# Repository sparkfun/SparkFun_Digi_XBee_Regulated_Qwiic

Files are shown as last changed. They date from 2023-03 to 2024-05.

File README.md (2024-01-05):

SparkFun Digi XBee® Explorer Regulated
========================================

SparkFun Digi XBee® Explorer Regulated (https://www.sparkfun.com/products/22032)

[*SparkFun Digi XBee® Explorer Regulated (22032)*](https://www.sparkfun.com/products/22032)

Unleash the power of Digi XBee® modules with the next-gen SparkFun Digi XBee® Explorer Regulated! This versatile breakout board bypasses a USB-C connection, packing all the XBee functionality you need alongside the power of Digi's newest XBee 3 modules (XBee 3 LTE-M/NB-IoT and XBee RR Pro) into a single, convenient solution. The SparkFun Digi XBee® Explorer Regulated is the perfect companion for any low-power cellular IoT project. Its simplicity, versatility, and robust features make it ideal for beginners and seasoned developers.

The SparkFun Digi XBee® Explorer Regulated streamlines your workflow, providing everything you need to get started. Power is provided through the PTH headers, and the board retains its power regulation capabilities. You can enable the Qwiic connector for all those lovely I<sup>2</sup>C sensors and Reset and D0 buttons.

Repository Contents
-------------------

* **/Hardware** - Eagle design files (.brd, .sch)
* **/Production** - Production panel files (.brd)
* **/docs** - Related software for the Sparkfun Digi XBee® Arduino Shield

Documentation
--------------
* **[Hookup Guide](http://docs.sparkfun.com/SparkFun_Digi_XBee_Regulated_Qwiic)** - Basic hookup guide for the SparkFun Digi XBee® Explorer Regulated.

License Information
-------------------

This product is _**open source**_! 

Please review the LICENSE.md file for license information. 

If you have any questions or concerns on licensing, please contact technical support on our [SparkFun forums](https://forum.sparkfun.com/viewforum.php?f=152).

Distributed as-is; no warranty is given.

- Your friends at SparkFun.

_<COLLABORATION CREDIT>_

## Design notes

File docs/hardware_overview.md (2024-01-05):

---
icon: material/cog
---

## Digi XBee Smart Modem Socket

We've kept the Digi XBee socket consistent with the Digi XBee pinout, so this breakout board is backwards compatible. In order to take full advantage of this board, we recommend one of the newer Digi XBee boards. The [Digi XBee 3 Low-Power LTE-M/NB-IoT, GNSS, no SIM](https://www.sparkfun.com/products/22329) is a great bet. 

<figure markdown>
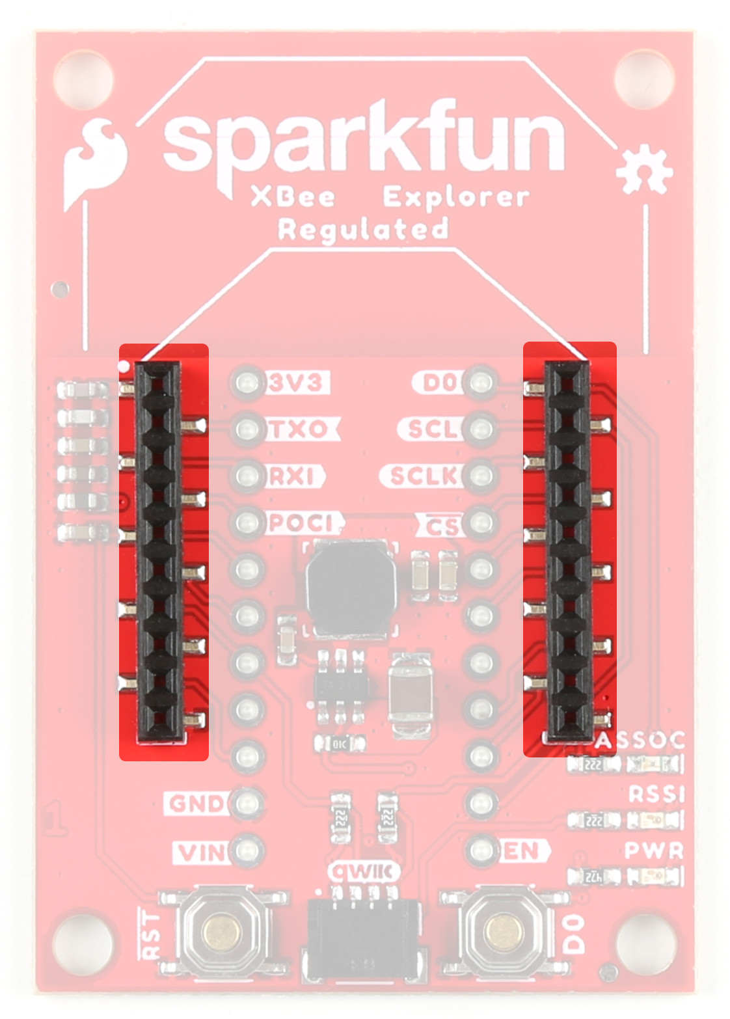
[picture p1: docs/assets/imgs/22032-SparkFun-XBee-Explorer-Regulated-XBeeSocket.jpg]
Digi XBeeSocket

<figcaption markdown>XBeeSocket</figcaption>
</figure>

## Qwiic Connector

The Qwiic connector on the SparkFun Digi XBee® Explorer Regulated Board provides power and I<sup>2</sup>C connectivity to Qwiic breakout boards. Note that I<sup>2</sup>C functionality is not enabled by default. 

<figure markdown>
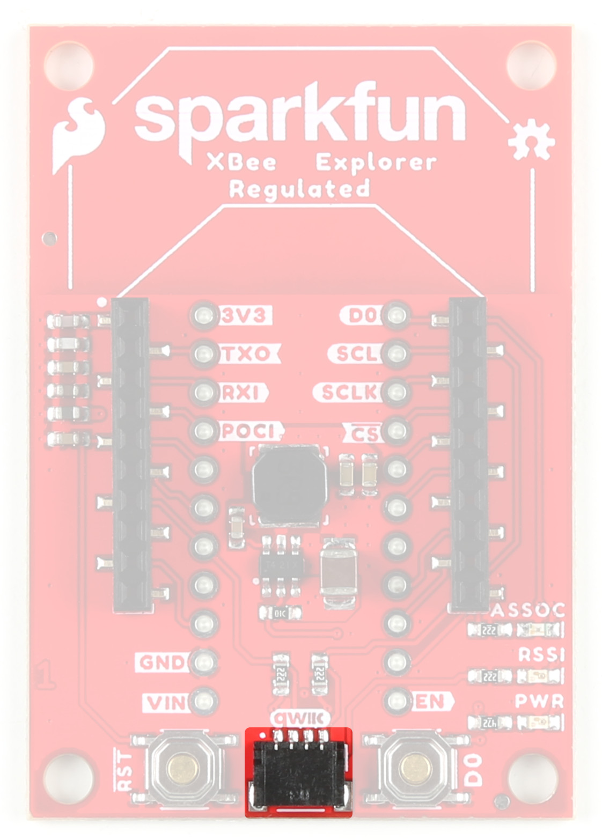
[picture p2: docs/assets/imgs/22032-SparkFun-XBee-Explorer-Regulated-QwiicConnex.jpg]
Qwiic Connector

<figcaption markdown>Qwiic Connector</figcaption>
</figure>

## Buck Converter - AP63203

The AP63203 is a 2A, synchronous buck converter with a wide input voltage range that fully integrates a 125mΩ high-side power MOSFET and a 68mΩ lowside power MOSFET to provide high-efficiency step-down DC/DC conversion. VIN range is <b>3.8V-5.5V</b>. Output is 2A max. 

<figure markdown>
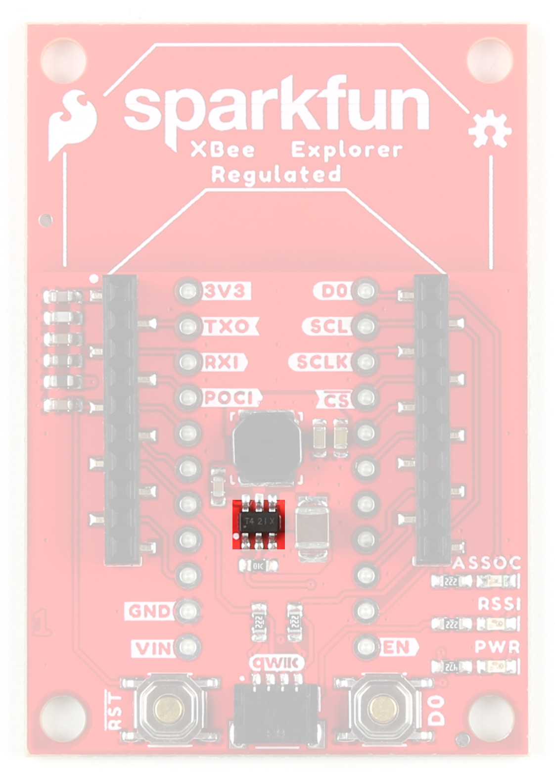
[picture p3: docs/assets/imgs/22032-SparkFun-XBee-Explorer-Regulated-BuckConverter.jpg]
AP63203 Buck Converter

<figcaption markdown>AP63203 Buck Converter</figcaption>
</figure>

## GPIO

We've broken out the Digi XBee pins to plated through holes on either side of the board. 

<figure markdown>
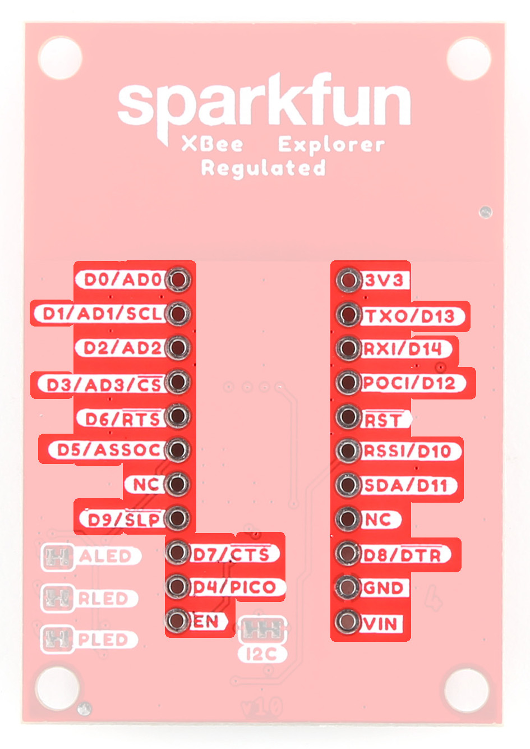
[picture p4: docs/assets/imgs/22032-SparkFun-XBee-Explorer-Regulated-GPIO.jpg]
GPIO

<figcaption markdown>GPIO</figcaption>
</figure>

## Buttons 

There are two buttons - D0 and RST. RST resets the board without power cycling it, D0 is user-defined. 

<figure markdown>
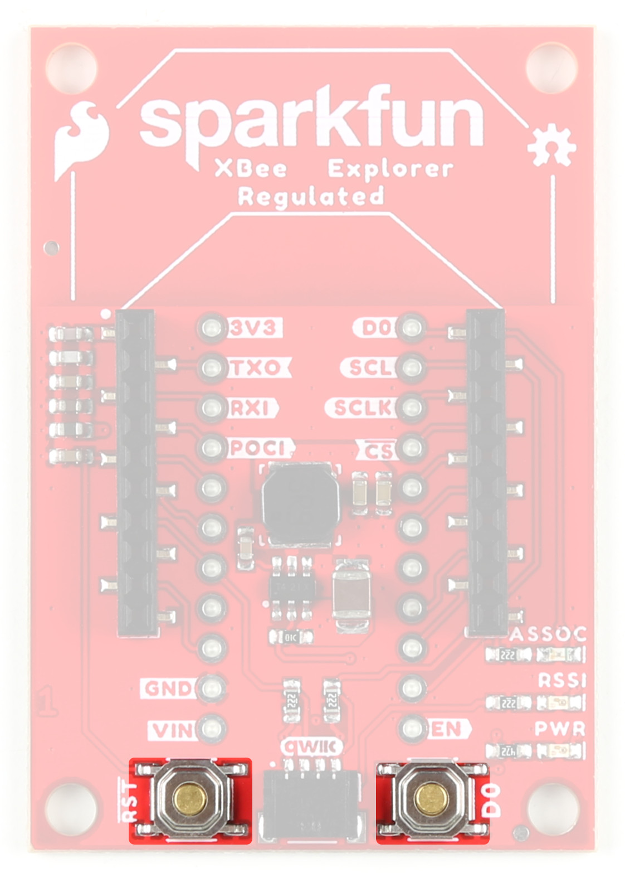
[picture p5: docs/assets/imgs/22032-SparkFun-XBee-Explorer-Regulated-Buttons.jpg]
Reset and D0 Buttons

<figcaption markdown>Reset and D0 Buttons</figcaption>
</figure>

## LEDs

There are a number of LEDs on the board: 

<figure markdown>
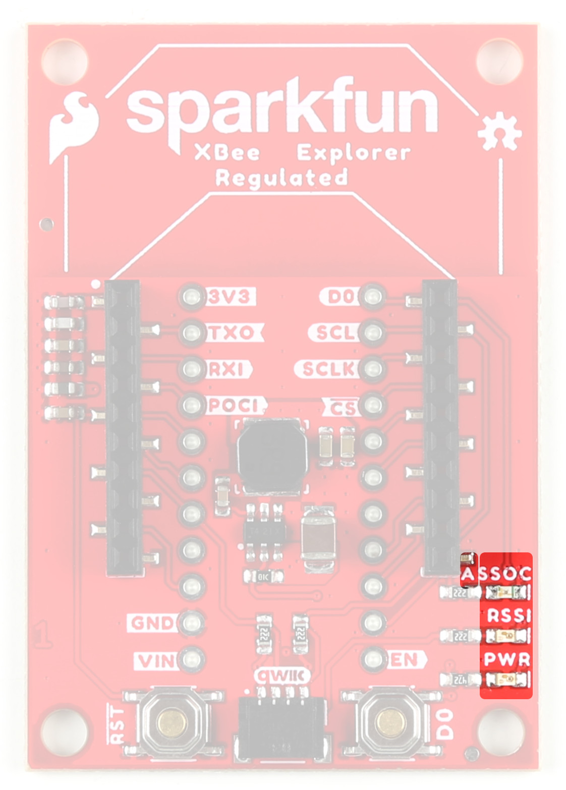
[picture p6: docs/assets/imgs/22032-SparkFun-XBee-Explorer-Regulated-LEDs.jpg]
LEDs

<figcaption markdown>LEDs</figcaption>
</figure>

### PWR

Lights up when power is provided to the board. 

### ASSOC
The LED on the development board blinks when the Digi XBee is registered to the cellular network.

| Blink | Timing | Meaning |
| --- | --- | --- |
| On | Solid | Not joined to a mobile network |
| Double Blink | ½ second | The last TCP/UDP/SMS attempt failed. If the LED has this pattern, you may need to check DI (Remote Manager Indicator) or CI (Protocol/Connection Indication) for the cause of the error. | 
| Single blink | 1 Second | Normal Operation |

### RSSI 
Received Signal Strength Indicator - When configured, this LED reflects the received signal strength. 

RSSI PWM
The RSSI/PWM output is enabled continuously unlike other Digi XBee products where the output is enabled for a short period of time after each received transmission. If running on the XBIB development board, DIO10 is connected to the RSSI LEDs, which may be interpreted as follows:

| PWM duty cycle | Number of LEDs turned on | Received signal strength (dBm) |
| --- | --- | --- |
| 79.39% or more | 3 | 83 dBm or higher |
| 62.42% to 79.39% | 2 | -93 to -83 dBm |
| 45.45% to 62.42% | 1 | -103 to -93 dBm |
| Less than 45.45% | 0 | Less than -103 dBm, or no cellular network connection |

## Jumpers

### ALED/PLED/RLED

If power consumption is an issue (or if you just don't like the LEDs), cut the respective jumper to sever power to the LED. 

* PLED: Red
* ALED: Blue
* RLED (RSSI): Yellow

<figure markdown>
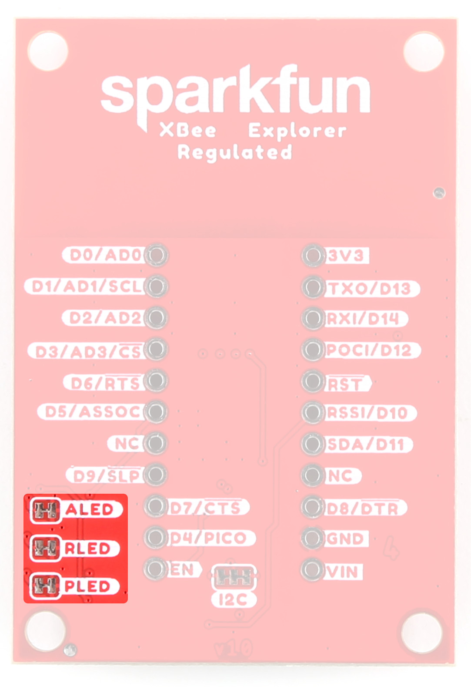
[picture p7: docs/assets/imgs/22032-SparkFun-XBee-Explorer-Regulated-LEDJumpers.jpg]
LED Jumpers

<figcaption markdown>LED Jumpers</figcaption>
</figure>

### I2C 

The I<sup>2</sup>C jumper pulls the SDA and SCL pins to VDD (normally 3.3V) through two 2.2K Ohm resistors. If you have multiple Qwiic devices on the same bus you may want to disable these by opening the jumper (assuming they are also operating at 3.3V logic).

<figure markdown>
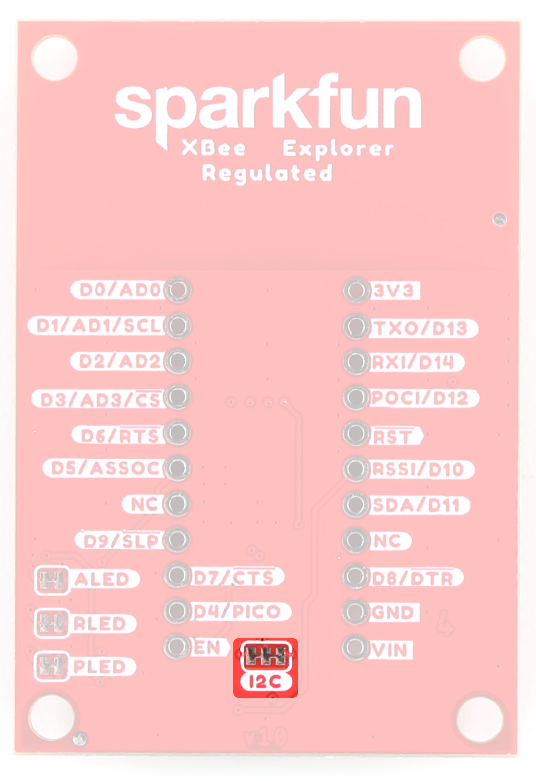
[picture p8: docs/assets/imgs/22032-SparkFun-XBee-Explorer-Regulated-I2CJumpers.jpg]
I2C Jumper

<figcaption markdown>I<sup>2</sup>C Jumper</figcaption>
</figure>

## Board Outline

The overall size of the SparkFun Digi XBee® Explorer Regulated is 1.4" by 2.05". For specific measurements, see the image below. 

<figure markdown>
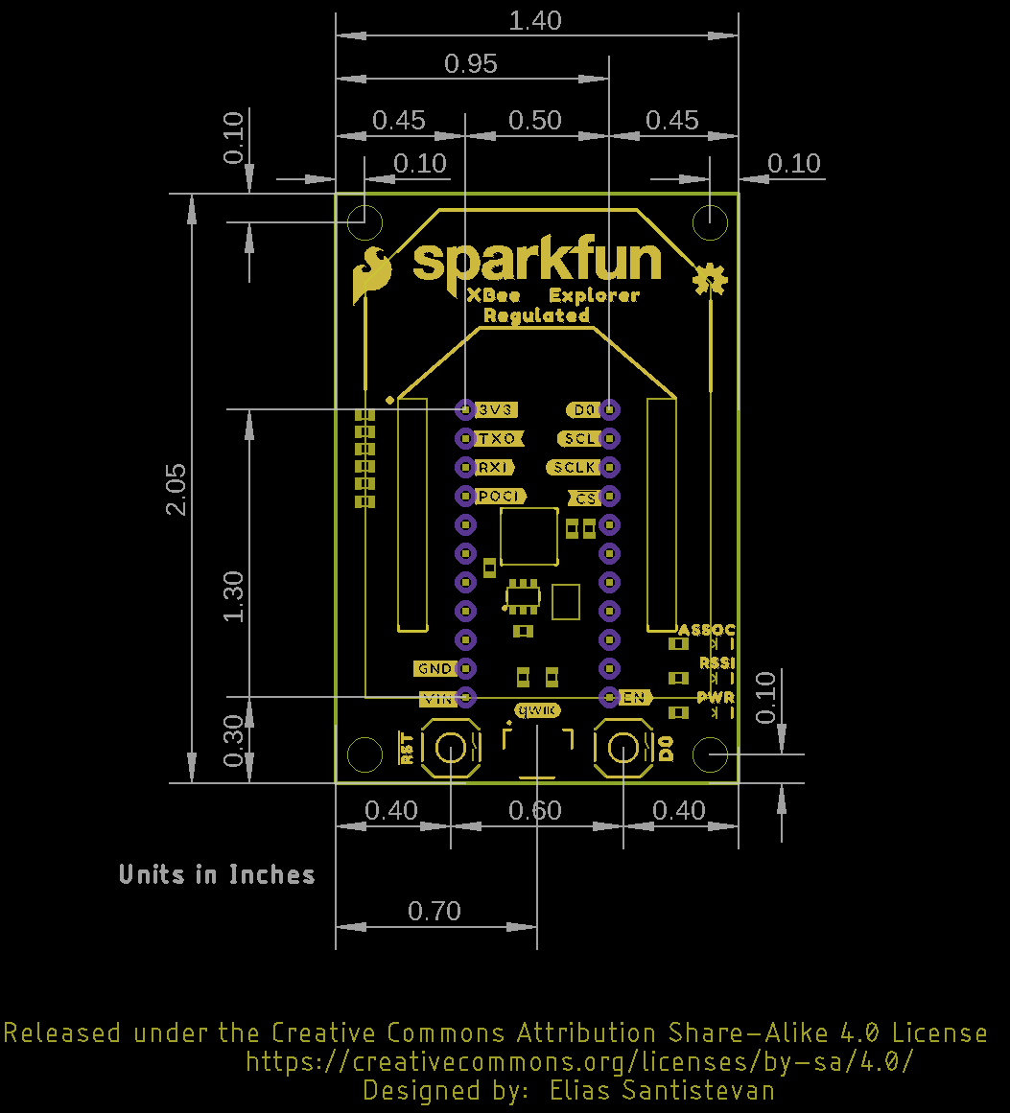
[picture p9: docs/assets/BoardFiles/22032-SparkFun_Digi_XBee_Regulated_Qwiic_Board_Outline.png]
Board Outline

<figcaption markdown>Board Outline</figcaption>
</figure>

??? tip "Need more measurements?"
	For more information about the board's dimensions, users can download the [Eagle files](assets/board_files/SparkFun_Digi_XBee_Regulated_Qwiic_EagleFiles.zip) for the board. These files can be opened in Eagle and additional measurements can be made with the dimensions tool.

	??? info ":octicons-download-16:{ .heart } Eagle - Free Download!"
		Eagle is a [CAD]("computer-aided design") program for electronics that is free to use for hobbyists and students. However, it does require an account registration to utilize the software.

		<center>
		[Download from<br>:autodesk-primary:{ .autodesk }](https://www.autodesk.com/products/eagle/free-download "Go to downloads page"){ .md-button .md-button--primary width="250px" }
		</center>
	
	??? info ":straight_ruler: Dimensions Tool"
		This video from Autodesk demonstrates how to utilize the dimensions tool in Eagle, to include additional measurements:

		<center>
		<div class="video">
		<iframe src="https://www.youtube.com/embed/dZLNd1FtNB8" title="EAGLE Dimension Tool" frameborder="0" allow="accelerometer; autoplay; clipboard-write; encrypted-media; gyroscope; picture-in-picture" allowfullscreen></iframe>
		</div>
		</center>

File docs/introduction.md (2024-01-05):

---
icon: material/book-open-page-variant
---

<div class="grid cards desc" markdown>

-    <a href="https://www.sparkfun.com/products/22560">
    **SparkFun Digi XBee® Explorer Regulated**<br>
    **SKU:** WRL-22560

    ---

    <figure markdown>
    Product Thumbnail
    </figure></a>
    
-    Unleash the power of Digi XBee® modules with the next-gen SparkFun Digi XBee® Explorer Regulated! This versatile breakout board bypasses a USB-C connection, packing all the XBee functionality you need alongside the power of Digi's newest XBee 3 modules (XBee 3 LTE-M/NB-IoT and XBee RR Pro) into a single, convenient solution. The SparkFun Digi XBee® Explorer Regulated is the perfect companion for any low-power cellular IoT project. Its simplicity, versatility, and robust features make it ideal for beginners and seasoned developers. The SparkFun Digi XBee® Explorer Regulated streamlines your workflow, providing everything you need to get started. Power is provided through the PTH headers, and the board retains its power regulation capabilities. You can enable the Qwiic connector for all those lovely I<sup>2</sup>C sensors and Reset and D0 buttons.

    <center>
    [Purchase from SparkFun :fontawesome-solid-cart-plus:{ .heart }](https://www.sparkfun.com/products/21636){ .md-button .md-button--primary }
    </center>

</div>

## Required Materials

To follow along with this tutorial, you will need the following materials. You may not need everything though depending on what you have. Add it to your cart, read through the guide, and adjust the cart as necessary.

<div class="grid cards" markdown>

-   <a href="https://www.sparkfun.com/products/22032">
    <figure markdown>
    Product Thumbnail
    </figure>

    ---

    **SparkFun Digi XBee® Explorer Regulated**<br>
    WRL-22032</a>

-   <a href="https://www.sparkfun.com/products/22329">
    <figure markdown>
    Product Thumbnail
    </figure>

    ---

    **Digi XBee 3 Low-Power LTE-M/NB-IoT, GNSS, no SIM**<br>
    WRL-22329</a>

-   <a href="https://www.sparkfun.com/products/14743">
    <figure markdown>
    Product Thumbnail
    </figure>

    ---

    **USB 3.1 Cable A to C - 3 Foot**<br>
    CAB-14743</a>

</div>

## Suggested Reading

As a more professionally oriented product, we will skip over the more fundamental tutorials (i.e. [**Ohm's Law**](https://learn.sparkfun.com/tutorials/voltage-current-resistance-and-ohms-law) and [**What is Electricity?**](https://learn.sparkfun.com/tutorials/what-is-electricity)). However, below are a few tutorials that may help users familiarize themselves with various aspects of the board.

<div class="grid cards hide col-4" markdown align="center">

-   <a href="https://www.sparkfun.com/pages/xbee_guide">
    <figure markdown>
    XBee Buying Guide
    </figure>
    </a>
    <a href="https://www.sparkfun.com/pages/xbee_guide">**XBee Buying Guide**
    </a>

-   <a href="https://learn.sparkfun.com/tutorials/exploring-xbees-and-xctu">
    <figure markdown>
    Exploring XBees and XCTU
    </figure>
    </a>
    <a href="https://learn.sparkfun.com/tutorials/exploring-xbees-and-xctu">**Exploring XBees and XCTU**
    </a>    

-   <a href="https://learn.sparkfun.com/tutorials/serial-communication">
    <figure markdown>
    Serial Communication
    </figure>
    </a>
    <a href="https://learn.sparkfun.com/tutorials/serial-communication">**Serial Communication**
    </a>    

</div>

<center>
<div align="center">
    <div style="top:5px;left:5px;background-color:Gray;position:relative">
        <div style="top:-5px;left:-5px;background-color:#ffffff;position:relative;border:1px solid black;">
            <a href="https://www.sparkfun.com/qwiic">Qwiic Connect System</a>
        </div>
    </div>
</div>
</center>

The SparkFun Digi XBee® Explorer Regulated Board takes advantage of the [Qwiic connect system](https://www.sparkfun.com/qwiic). We recommend familiarizing yourself with the **Logic Levels** and **I<sup>2</sup>C** tutorials. Click on the banner above to learn more about [Qwiic products](https://www.sparkfun.com/qwiic).

<center>
    <iframe width="600" height="327" src="https://www.youtube.com/embed/x0RDEHqFIF8" title="SparkFun's Qwiic Connect System" frameborder="0" allow="accelerometer; autoplay; clipboard-write; encrypted-media; gyroscope; picture-in-picture" allowfullscreen></iframe>
</center>

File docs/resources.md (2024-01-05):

For more resources related to the SparkFun Digi XBee® Explorer Regulated, check out the links listed here: 

* [Product Page](https://www.sparkfun.com/products/22032){ target="_blank" }
* [Schematic (PDF)](assets/BoardFiles/22032-SparkFun_Digi_XBee_Regulated_Qwiic-Schematic.pdf){ target="_blank" }
* [Eagle Files](assets/BoardFiles/SparkFun_Digi_XBee_Regulated_Qwiic_EagleFiles.zip){ target="_blank" }
* [Board Outline (PNG)](assets/BoardFiles/22032-SparkFun_Digi_XBee_Regulated_Qwiic_Board_Outline.png){ target="_blank" }
* [GitHub Hardware Repo](https://github.com/sparkfun/SparkFun_Digi_XBee_Regulated_Qwiic){ target="_blank" }

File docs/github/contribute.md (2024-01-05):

# Contribute: Make an Augmentation!
Spot an improvement opportunity? Feel free to contribute to our open-source design and documentation. 

## :material-file-document-multiple:&nbsp;Improve our Documentation
All of this documentation can be modified by you! Please help us make it better.

* These pages are contained in the [`docs` folder](https://github.com/sparkfun/SparkFun_Digi_XBee_Regulated_Qwiic/tree/main/docs) of the SparkFun Digi XBee® Explorer Regulated repository](https://github.com/sparkfun/SparkFun_Digi_XBee_Regulated_Qwiic).

<!-- ### :material-source-pull:&nbsp;Submit a Correction -->
### Submit a Correction

1. With a GitHub account, [fork this repository](https://github.com/sparkfun/SparkFun_Digi_XBee_Regulated_Qwiic/fork).
2. Add your corrections or improvements to the markdown file.
3. File a pull request with your changes, and enjoy making the ~~words~~ ~~worlds~~ world a better place.
	* Once received, the documentation specialist will automatically be notified.
	* We will review your suggested improvements to make sure they are correct and fit within our documentation standards.

## :material-cog:&nbsp;Improve our Hardware Design
All of our designs are open-source! Please help us make it better.

* Our board design files are contained in the [`Hardware` folder](https://github.com/sparkfun/SparkFun_Digi_XBee_Regulated_Qwiic/tree/main/Hardware) of the [SparkFun Digi XBee® Explorer Regulated repository](https://github.com/sparkfun/SparkFun_Digi_XBee_Regulated_Qwiic).

<!-- ### :material-source-pull:&nbsp;Submit a Design Enhancement -->
### Submit a Design Enhancement

1. With a GitHub account, [fork this repository](https://github.com/sparkfun/SparkFun_Digi_XBee_Regulated_Qwiic/fork).
2. Add your design augmentation(s)
3. File a pull request with your changes, and enjoy making the ~~words~~ ~~worlds~~ world a better place.
	1. Once received, the engineer in charge of the original design will automatically be notified.
	2. We will review your suggested improvement(s) to verify that they are within our board design standards and meet our product design requirements.
	3. If approved, we will flag these changes for our next board revision. Congrats! 🍻

		!!! info
			Even if your suggestion is accepted, these changes may not be immediately available for purchase. We may have to cycle through our current product inventory first.

## Contributors&nbsp;:clap:
Let's provide some recognition to the contributors for this project!

GitHub Contributors Image
<br>


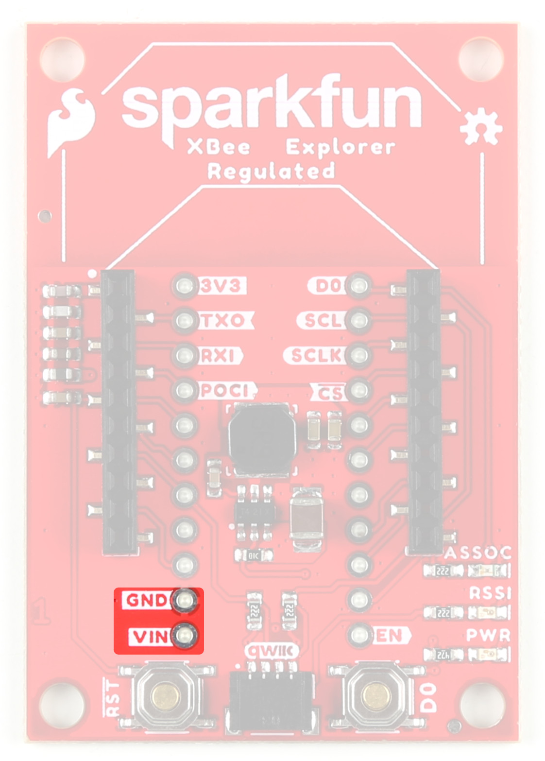
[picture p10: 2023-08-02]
docs/assets/imgs/22032-SparkFun-XBee-Explorer-Regulated-PowerPins.jpg

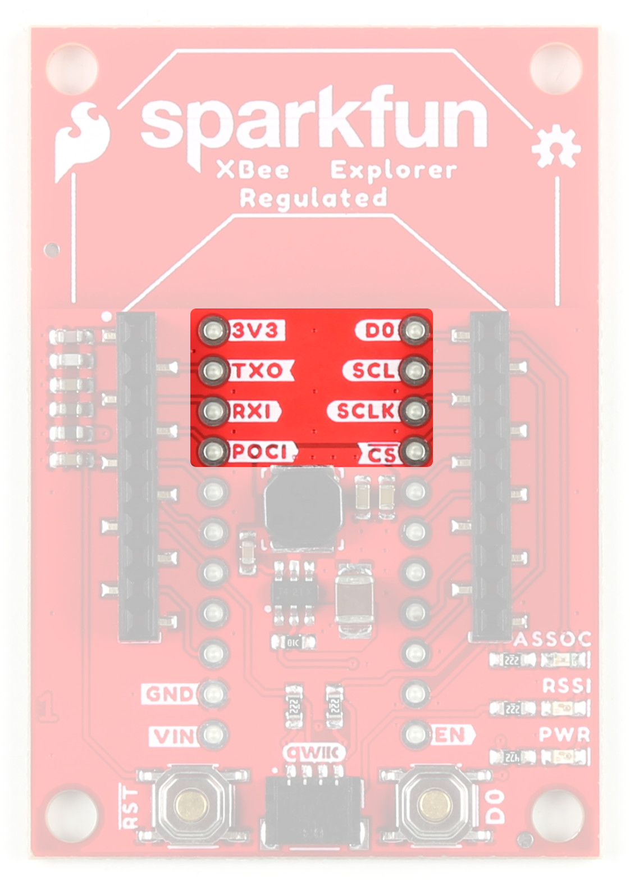
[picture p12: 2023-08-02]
docs/assets/imgs/22032-SparkFun-XBee-Explorer-Regulated-PTHs.jpg

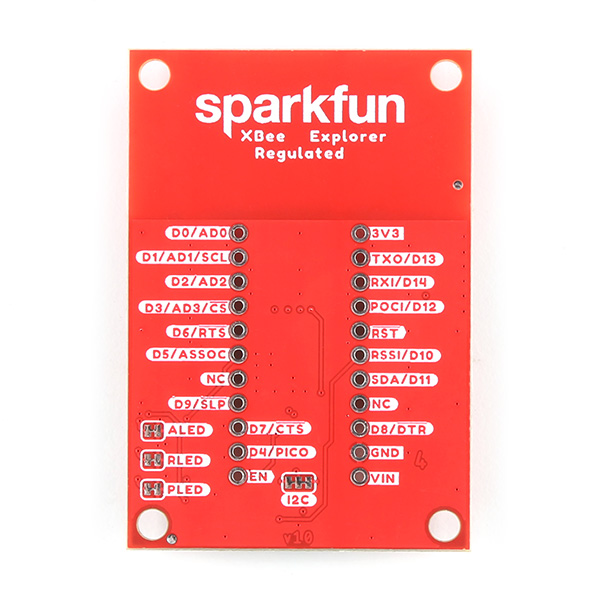
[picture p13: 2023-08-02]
docs/assets/imgs/22032/Resized/22032- XBee Explorer Regulated- 03.jpg

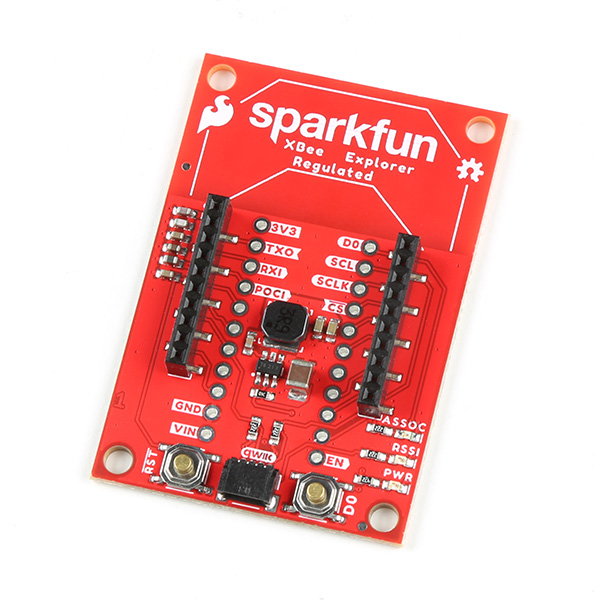
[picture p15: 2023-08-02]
docs/assets/imgs/22032-XBee-Explorer-Regulated-01.jpg

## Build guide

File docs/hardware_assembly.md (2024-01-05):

---
icon: fontawesome/solid/screwdriver-wrench
---

Note the white silkscreen on the Shield PCB - this will help orient your Digi XBee as you're plugging it in. Make sure to match up the Digi XBee's two diagonal edges with the two diagonal lines on the PCB.

<figure markdown>
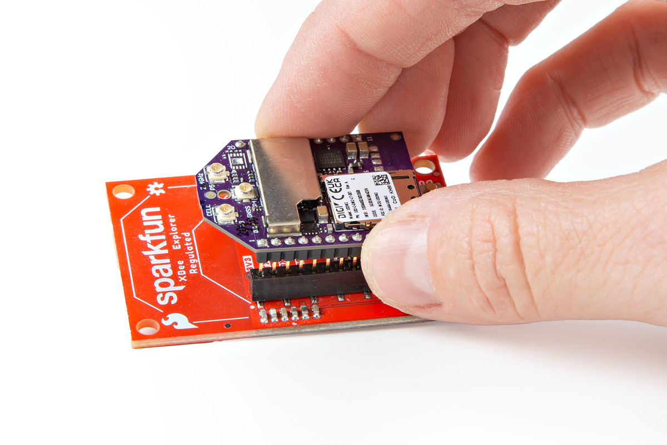
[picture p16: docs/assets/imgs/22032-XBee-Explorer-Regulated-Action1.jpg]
Digi XBee unit being plugged into the SparkFun Digi XBee® Explorer Regulated

<figcaption markdown>Digi XBee unit being plugged into the SparkFun Digi XBee® Explorer Regulated</figcaption>
</figure>

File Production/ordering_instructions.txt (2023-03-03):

panel size, 122x171mm
PCB thickness, 1.6mm
number of layers, 4
soldermask color, Red
silkscreen color, White
oz copper, 1oz
finish, HASL lead free
stencils, top
pcs per panel, 9
min trace width, 0.1524mm / 0.0060in
min drill size, 0.3048mm / 0.0120in
filename to layer stackup 1/2/3/4: GTL, GL2, GL3, GBL

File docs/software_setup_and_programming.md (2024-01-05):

---
icon: simple/arduino
---

We have a number of tutorials detailing how to work with Digi XBees and their associated software. In particular, [XCTU](https://www.digi.com/products/embedded-systems/digi-xbee/digi-xbee-tools/xctu) is free software provided by Digi (the manufacturer of XBee), that provides a quick and easy way to configure and manage Digi XBees as well as test Digi XBee networks. 

If you haven't worked with XCTU before, head on over to our [Exploring XBees and XCTU tutorial](https://learn.sparkfun.com/tutorials/exploring-xbees-and-xctu/all#starting-with-x-ctu) to get set up.  

<center><table class="tg">
  <tr>
    <th class="tg-v0mg"><a href="https://learn.sparkfun.com/tutorials/exploring-xbees-and-xctu/all#starting-with-x-ctu">Exploring XBees and XCTU tutorial</a></th>
  </tr>
  <tr>
    <td class="tg-v0mg"><i>Exploring XBees and XCTU tutorial</i></td>
  </tr>
</table>
</center>

You might also check out this [XBee WiFi Hookup Guide](https://learn.sparkfun.com/tutorials/xbee-wifi-hookup-guide) if your project includes WiFi! 

<center>
<table class="tg">
  <tr>
    <th class="tg-v0mg"><a href="https://learn.sparkfun.com/tutorials/xbee-wifi-hookup-guide">XBee WiFi Hookup Guide</a></th>
  </tr>
  <tr>
    <td class="tg-v0mg"><i>XBee WiFi Hookup Guide</i></td>
  </tr>
</table>
</center>

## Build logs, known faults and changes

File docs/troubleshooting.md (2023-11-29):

---
icon: fontawesome/solid/question
---

!!! note
    <span class="glyphicon glyphicon-question-sign" aria-hidden="true"></span>
        <strong> Not working as expected and need help? </strong> <br /><br />

    If you need technical assistance and more information on a product that is not working as you expected, we recommend heading on over to the <a href="https://www.sparkfun.com/technical_assistance">SparkFun Technical Assistance</a> page for some initial troubleshooting. <br /><br />

    <div style="text-align: center"><a href="https://www.sparkfun.com/technical_assistance" target="sfe_technical_assistance" class="md-button">SparkFun Technical Assistance Page</a></div>

    If you don't find what you need there, the <a href="https://forum.sparkfun.com/index.php">SparkFun Forums</a> are a great place to find and ask for help. If this is your first visit, you'll need to <a href="https://forum.sparkfun.com/ucp.php?mode=register">create a Forum Account</a> to search product forums and post questions.<br /><br />

    <div style="text-align: center"><a href="https://forum.sparkfun.com/ucp.php?mode=register" class="md-button">Create New Forum Account</a>&nbsp;&nbsp;&nbsp;<a href="https://forum.sparkfun.com/index.php" class="md-button md-button--primary">Log Into SparkFun Forums</a></div>

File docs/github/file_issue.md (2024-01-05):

# Did we make a mistake?

Spot something wrong? Please let us know. 

<!-- Technical Assistance Box -->
!!! warning "Need Help?"
    If you need technical assistance or more information on a product that is not working as you expected, we recommend heading on over to the [SparkFun Technical Assistance](https://www.sparkfun.com/technical_assistanc) page for some initial troubleshooting. This **Submit Issues** page is not where users should seek assistance.

    <center>
    [SparkFun Technical Assistance Page](https://www.sparkfun.com/technical_assistance){ .md-button .md-button--primary }
    </center>
    
    If you can't find what you need there, the [SparkFun Forums](https://forum.sparkfun.com/index.php) is a great place to search the product forums and ask questions.
    
    !!! info "Account Registration Required"
        For your first visit to our forum, you'll need to create a [Forum Account](https://forum.sparkfun.com/ucp.php?mode=register) to post questions.

## Discrepancies in the Documentation

All of our documentation can be modified by you! Please help us make it better.

* The documentation files for these pages are contained in the [`docs` folder](https://github.com/sparkfun/SparkFun_Digi_XBee_Regulated_Qwiic/tree/main/docs) of the [SparkFun Digi XBee® Explorer Regulated repository](https://github.com/sparkfun/SparkFun_Digi_XBee_Regulated_Qwiic).

### 🔍 Spot something wrong?

If a section of the documentation is incorrect, please [open an issue](https://github.com/sparkfun/SparkFun_Digi_XBee_Regulated_Qwiic/issues) and let us know.

### Do you have a suggested correction?

1. With a GitHub account, [fork this repository](https://github.com/sparkfun/SparkFun_Digi_XBee_Regulated_Qwiic/fork).
2. Add your correction(s) or improvement(s) to the markdown file(s)
3. File a pull request with your changes, and enjoy making the ~~words~~ ~~worlds~~ world a better place.
	* Once received, the documentation specialist will automatically be notified.
	* We will review your suggested improvement(s) to make sure they are correct and fit within our documentation standards.

## Problems in the Hardware Design

All of our designs are open-source! Please help us make it better.

* Our board design files are contained in the [`Hardware` folder](https://github.com/sparkfun/SparkFun_Digi_XBee_Regulated_Qwiic/tree/main/Hardware) of the [SparkFun Digi XBee® Explorer Regulated repository](https://github.com/sparkfun/SparkFun_Digi_XBee_Regulated_Qwiic).

### Does something not make sense? 🤔

If part of the design is confusing, please [open an issue](https://github.com/sparkfun/SparkFun_Digi_XBee_Regulated_Qwiic/issues) and let us know.

### Did we forget to include an important function of the board? 🤦

If part of the board's functionality is missing, please [open an issue](https://github.com/sparkfun/SparkFun_Digi_XBee_Regulated_Qwiic/issues) and file a feature request.

!!! tip "Design Considerations"
	Please keep in mind that we may intentionally exclude certain functions of the board to meet our product design requirements.
	
	* *For example, our Qwiic Micro boards are intended to fit on a small board layout and only use I<sup>2</sup>C communication; therefore, we may not have the SPI and interrupt pins available for users.*

### Do you wish to contribute directly to improving the board design?

1. With a GitHub account, [fork this repository](https://github.com/sparkfun/SparkFun_Digi_XBee_Regulated_Qwiic/fork).
2. Add your design augmentation(s)
3. File a pull request with your changes, and enjoy making the ~~words~~ ~~worlds~~ world a better place.
	1. Once received, the engineer in charge of the original design will automatically be notified.
	2. We will review your suggested improvement(s) to verify that they are within our board design standards and meet our product design requirements.
	3. If approved, we will flag these changes for our next board revision. Congrats! 🍻

		!!! info
			Even if your suggestion is accepted, these changes may not be immediately available for purchase. We may have to cycle through our current product inventory first.

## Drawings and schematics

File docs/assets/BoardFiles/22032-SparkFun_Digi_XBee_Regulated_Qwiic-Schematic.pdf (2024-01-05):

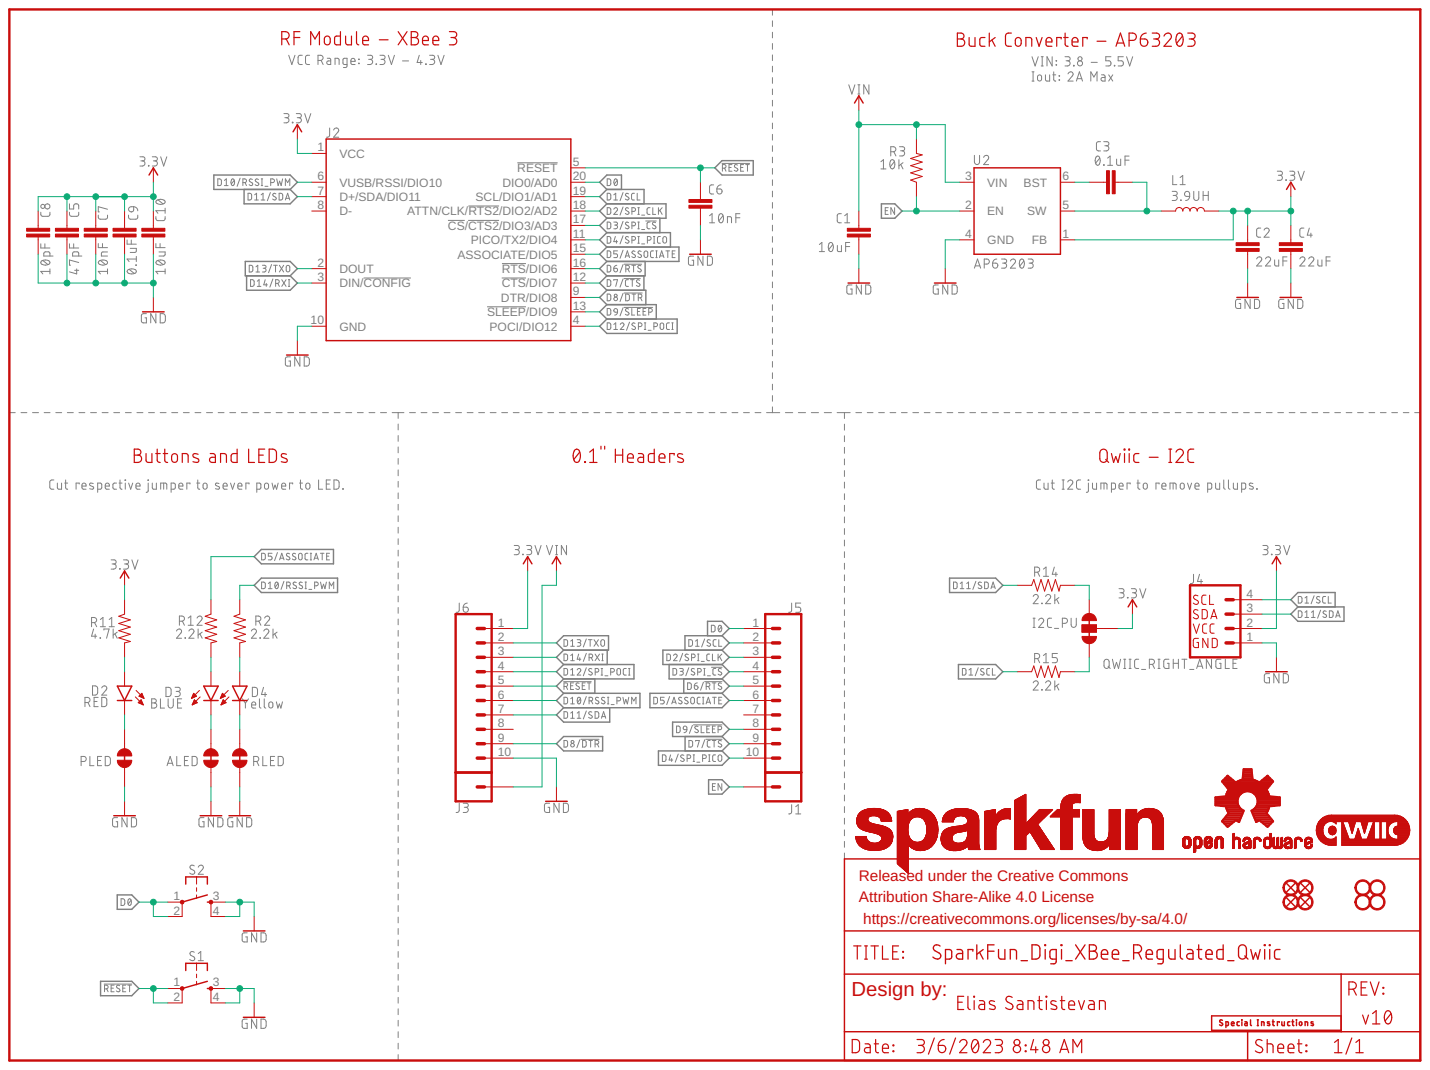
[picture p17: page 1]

Released under the Creative Commons Attribution Share-Alike 4.0 License

https://creativecommons.org/licenses/by-sa/4.0/

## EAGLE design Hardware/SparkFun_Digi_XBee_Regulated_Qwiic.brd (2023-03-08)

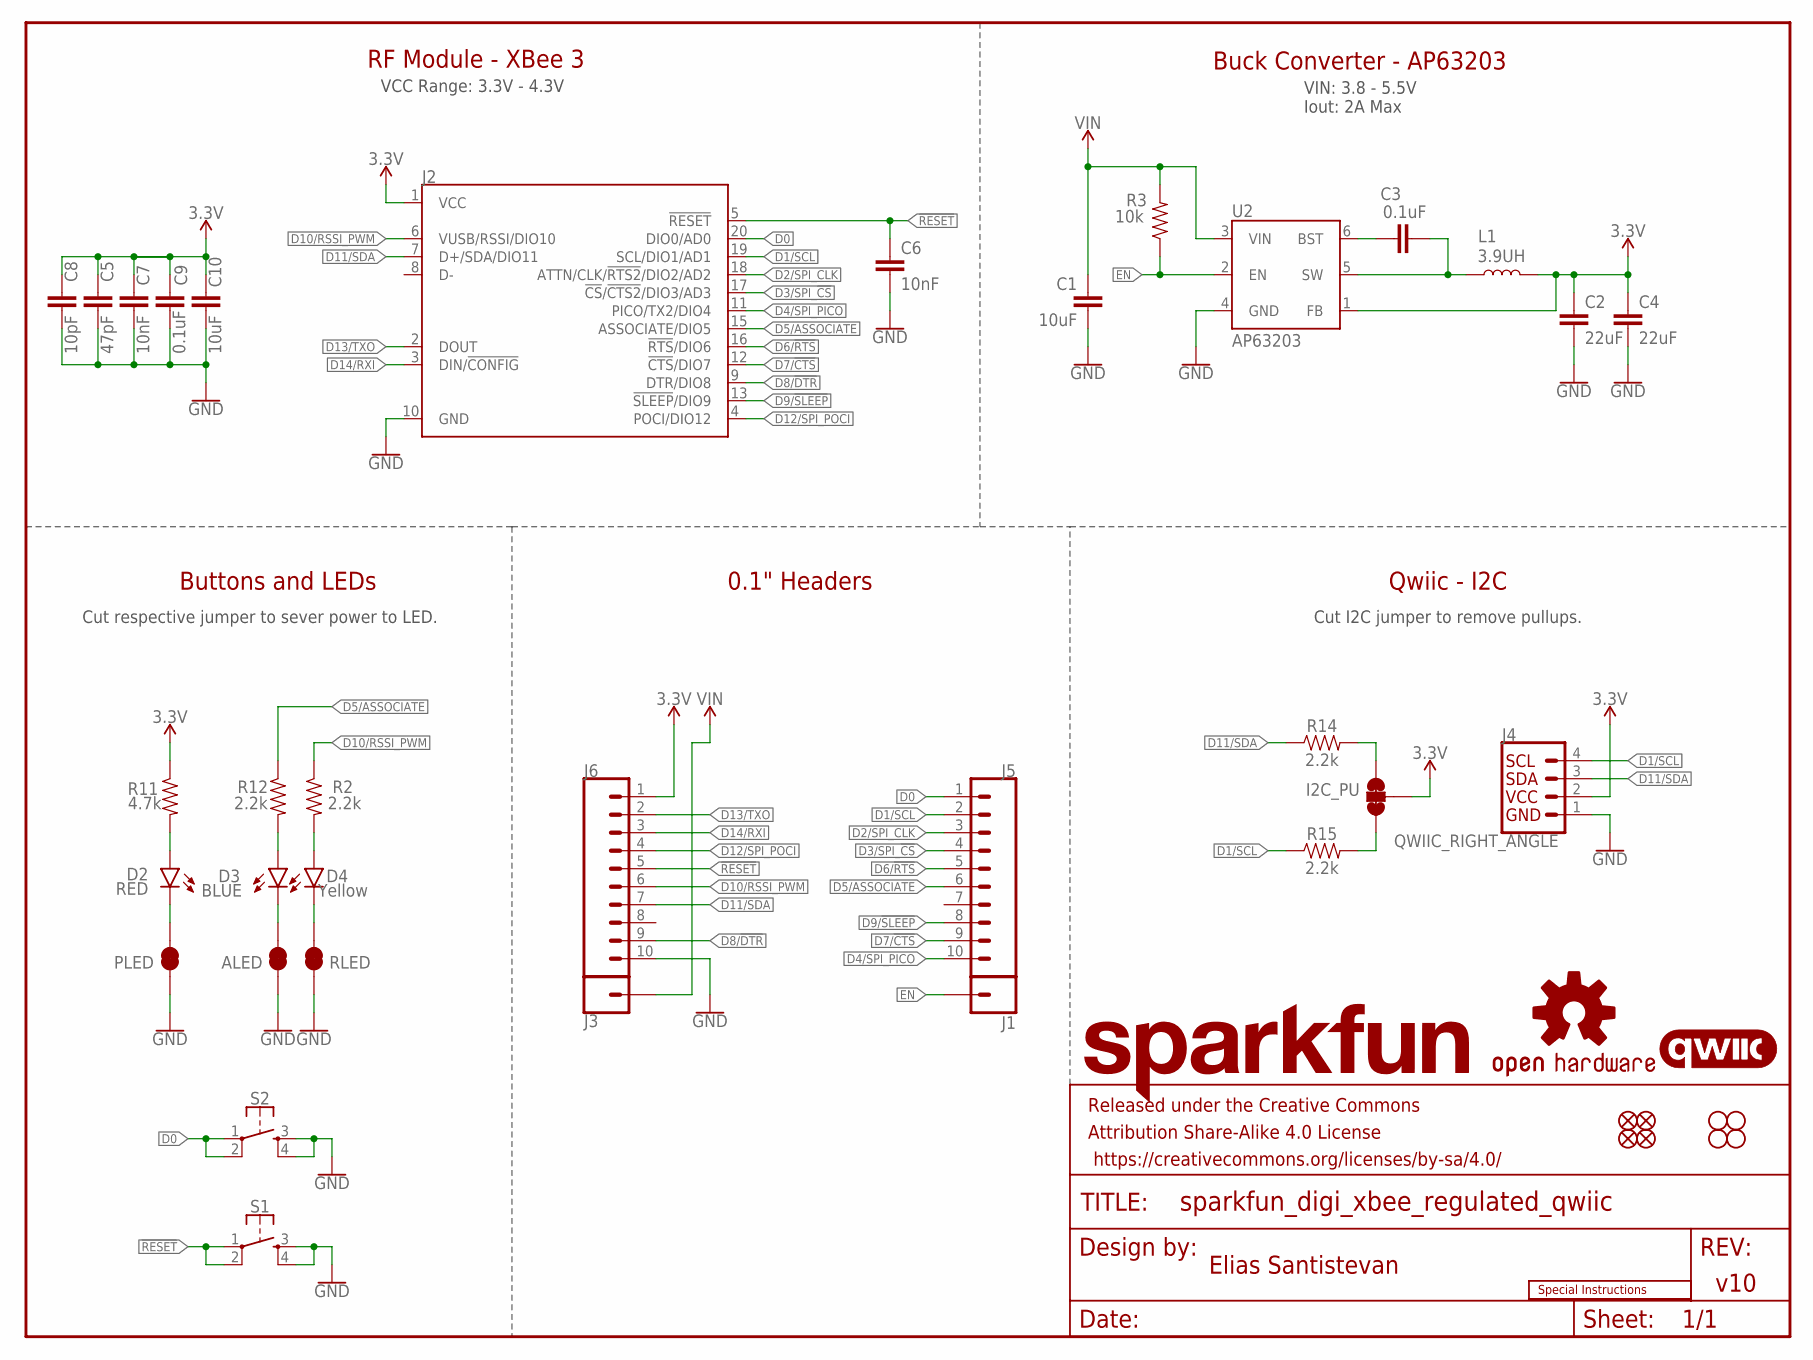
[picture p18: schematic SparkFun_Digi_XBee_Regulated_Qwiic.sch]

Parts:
ALED: JUMPER-SMT_2_NC_TRACE_SILK; SMT-JUMPER_2_NC_TRACE_SILK
C1: 10uF; 1210
C2, C4: 22uF; 0603
C3, C9: 0.1uF; 0603
C5: 47pF; 0603
C6, C7: 10nF; 0603
C8: 10pF; 0603
C10: 10uF; 0603
D2: RED; LED-0603
D3: BLUE; LED-0603
D4: Yellow; LED-0603
FD1, FD2, FD3, FD4: FIDUCIAL1X2; FIDUCIAL-1X2
FRAME2: FRAME-LETTER; CREATIVE_COMMONS
H1, H2, H3, H4: STAND-OFFTIGHT; STAND-OFF-TIGHT
I2C_PU: JUMPER-SMT_3_2-NC_TRACE_SILK; SMT-JUMPER_3_2-NC_TRACE_SILK
J1, J3: CONN_01PTH_NO_SILK_STAND; 1X01_NO_SILK_STAND
J2: XBEE_UPDATEXBEE_SMD; XBEE3-SMD
J4: QWIIC_RIGHT_ANGLE; JST04_1MM_RA
J5, J6: CONN_10NO_SILK_PTH_FEMALE; 1X10_NO_SILK
L1: 3.9UH; INDUCTOR_3.9UH
LOGO1: SPECIAL_INSTRUCTIONS-ORDERING; ORDERING_INSTRUCTIONS
LOGO2: OSHW-LOGOS; OSHW-LOGO-S
LOGO3: QWIIC_LOGO_4MM; QWIIC_4MM
LOGO4: SFE_LOGO_NAMEBLANK; BLANK
PLED: JUMPER-SMT_2_NC_TRACE_SILK; SMT-JUMPER_2_NC_TRACE_SILK
R2, R12, R14, R15: 2.2k; 0603
R3: 10k; 0603
R11: 4.7k; 0603
RLED: JUMPER-SMT_2_NC_TRACE_SILK; SMT-JUMPER_2_NC_TRACE_SILK
S1, S2: MOMENTARY-SWITCH-SPST-2-SMD-5.2MM-TALL; TACTILE_SWITCH_SMD_5.2MM
U2: AP63203; SOT23-6

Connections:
3.3V: C2.1, C4.1, C5.1, C7.1, C8.1, C9.1, C10.1, I2C_PU.2, J2.1 (VCC), J4.2, J6.1, L1.P$2 (2), R11.1, U2.1 (FB)
!RESET!: C6.1, J2.5 (!RESET!), J6.5, S1.1, S1.2
D0: J2.20 (DIO0/AD0), J5.1, S2.1, S2.2
D1/SCL: J2.19 (SCL/DIO1/AD1), J4.4, J5.2, R15.1
D2/SPI_CLK: J2.18 (ATTN/CLK/!RTS2!/DIO2/AD2), J5.3
D3/SPI_!CS!: J2.17 (!CS!/!CTS2!/DIO3/AD3), J5.4
D4/SPI_PICO: J2.11 (PICO/TX2/DIO4), J5.10
D5/ASSOCIATE: J2.15 (ASSOCIATE/DIO5), J5.6, R12.1
D6/!RTS!: J2.16 (!RTS!/DIO6), J5.5
D7/!CTS!: J2.12 (!CTS!/DIO7), J5.9
D8/!DTR!: J2.9 (DTR/DIO8), J6.9
D9/!SLEEP!: J2.13 (!SLEEP!/DIO9), J5.8
D10/RSSI_PWM: J2.6 (VUSB/RSSI/DIO10), J6.6, R2.1
D11/SDA: J2.7 (D+/SDA/DIO11), J4.3, J6.7, R14.1
D12/SPI_POCI: J2.4 (POCI/DIO12), J6.4
D13/TXO: J2.2 (DOUT), J6.2
D14/RXI: J2.3 (DIN/!CONFIG!), J6.3
EN: J1.1, R3.1, U2.2 (EN)
GND: ALED.1, C1.2, C2.2, C4.2, C5.2, C6.2, C7.2, C8.2, C9.2, C10.2, J2.10 (GND), J4.1, J6.10, PLED.1, RLED.1, S1.3, S1.4, S2.3, S2.4, U2.4 (GND)
unnamed: C3.1, U2.6 (BST)
unnamed: D4.A, R2.2
unnamed: D4.C, RLED.2
unnamed: D2.A, R11.2
unnamed: C3.2, L1.P$1 (1), U2.5 (SW)
unnamed: I2C_PU.3, R14.2
unnamed: D3.A, R12.2
unnamed: I2C_PU.1, R15.2
unnamed: ALED.2, D3.C
unnamed: D2.C, PLED.2
VIN: C1.1, J3.1, R3.2, U2.3 (VIN)

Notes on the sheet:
VCC Range: 3.3V - 4.3V
Buck Converter - AP63203
Qwiic - I2C
v10
Elias Santistevan
Buttons and LEDs
VIN: 3.8 - 5.5V Iout: 2A Max
Cut I2C jumper to remove pullups.
Cut respective jumper to sever power to LED.
RF Module - XBee 3
0.1" Headers

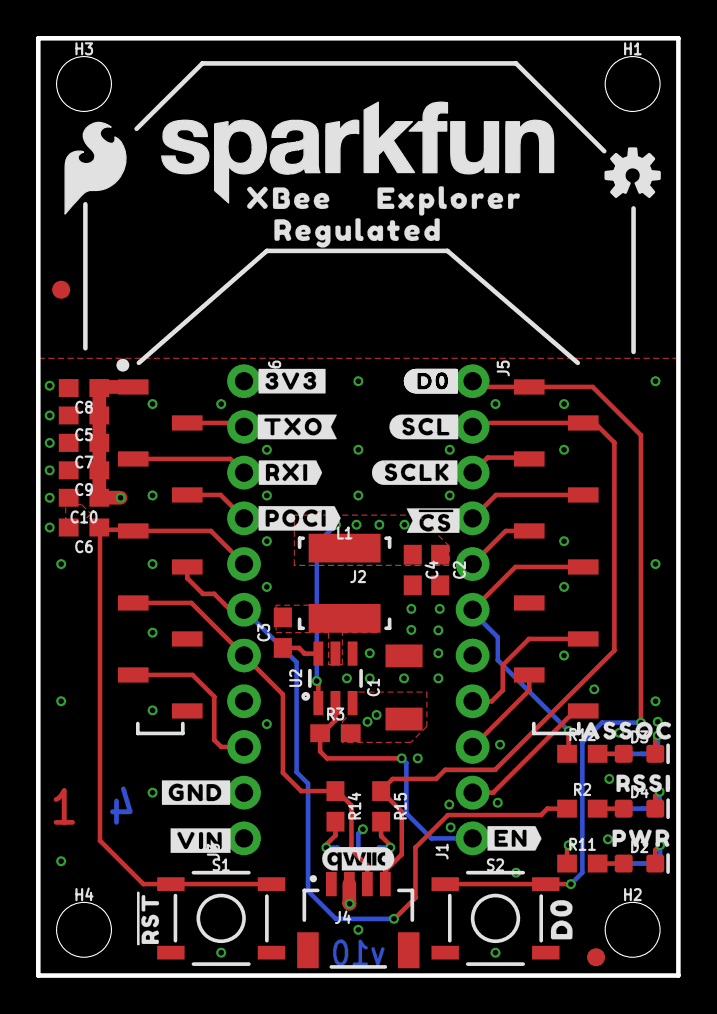
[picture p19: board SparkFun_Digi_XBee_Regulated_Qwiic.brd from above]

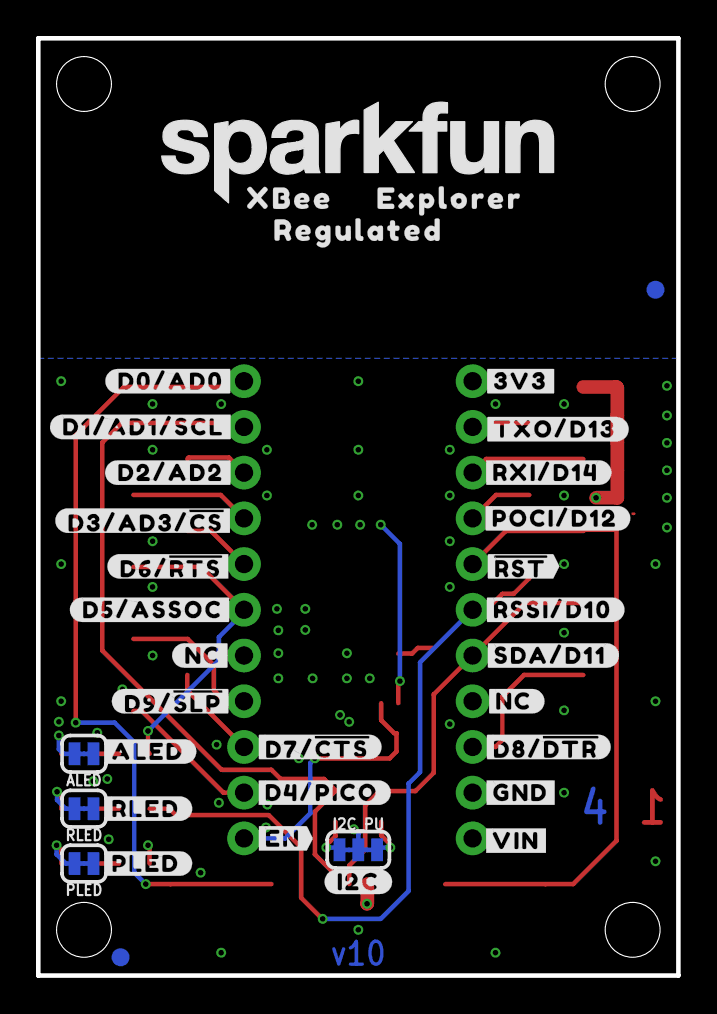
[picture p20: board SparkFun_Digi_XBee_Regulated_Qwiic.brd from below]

Board: 4 copper layers, 35.6 x 52.1 mm, 98 parts (36 on the bottom side), 30 nets.

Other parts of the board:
U$1, U$12: #GND#0
U$2, U$63: SFE_LOGO_NAME_.2
U$3, U$6: #EN#17
U$4: #NC#1
U$5: #NC#3
U$7: #D7##CTS##26
U$8: #D0#AD0#18
U$9, U$44: #3V3#1
U$10: #D4#PICO#25
U$11: #RLED#22
U$13: #D8##DTR##27
U$14: #RSSI#D10#17
U$15: #SDA#D11#9
U$16: ##RST##15
U$17: #POCI#D12#24
U$18: #RXI#D14#15
U$19: #D2#AD2#19
U$20: #D6##RTS##25
U$21: #TXO#8
U$22: #TXO#D13#13
U$23, U$33: EXPLORER1344
U$24, U$29: REGULATED1343
U$25, U$28: XBEE340
U$26: #I2C#33
U$27: #RXI#7
U$30: #RST#30
U$31, U$65: #D0#3
U$32: #D1#AD1#SCL#8
U$34: #D3#AD3##CS##23
U$35: #D5#ASSOC#25
U$36: #D9##SLP##28
U$40: D03
U$42: PWR26
U$43: ASSOC27
U$45: #POCI#32
U$46, U$66: #VIN#4
U$49: #ALED#21
U$52: #PLED#20
U$59: ##CS##26
U$60: #SCLK#33
U$61: SFE_LOGO_FLAME_.2
U$62: RSSI31
U$64: #SCL#9

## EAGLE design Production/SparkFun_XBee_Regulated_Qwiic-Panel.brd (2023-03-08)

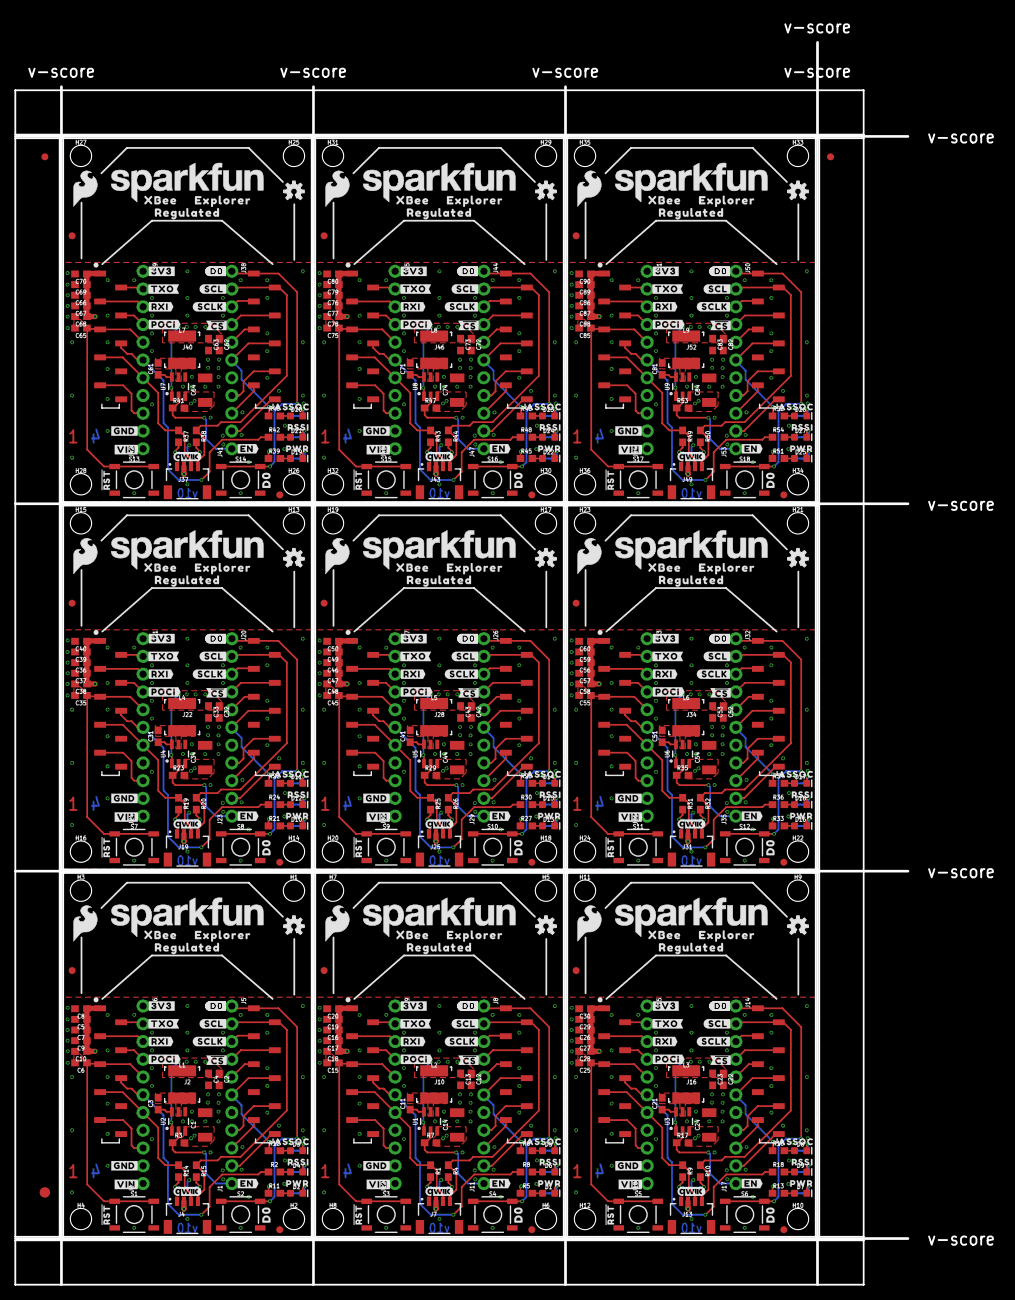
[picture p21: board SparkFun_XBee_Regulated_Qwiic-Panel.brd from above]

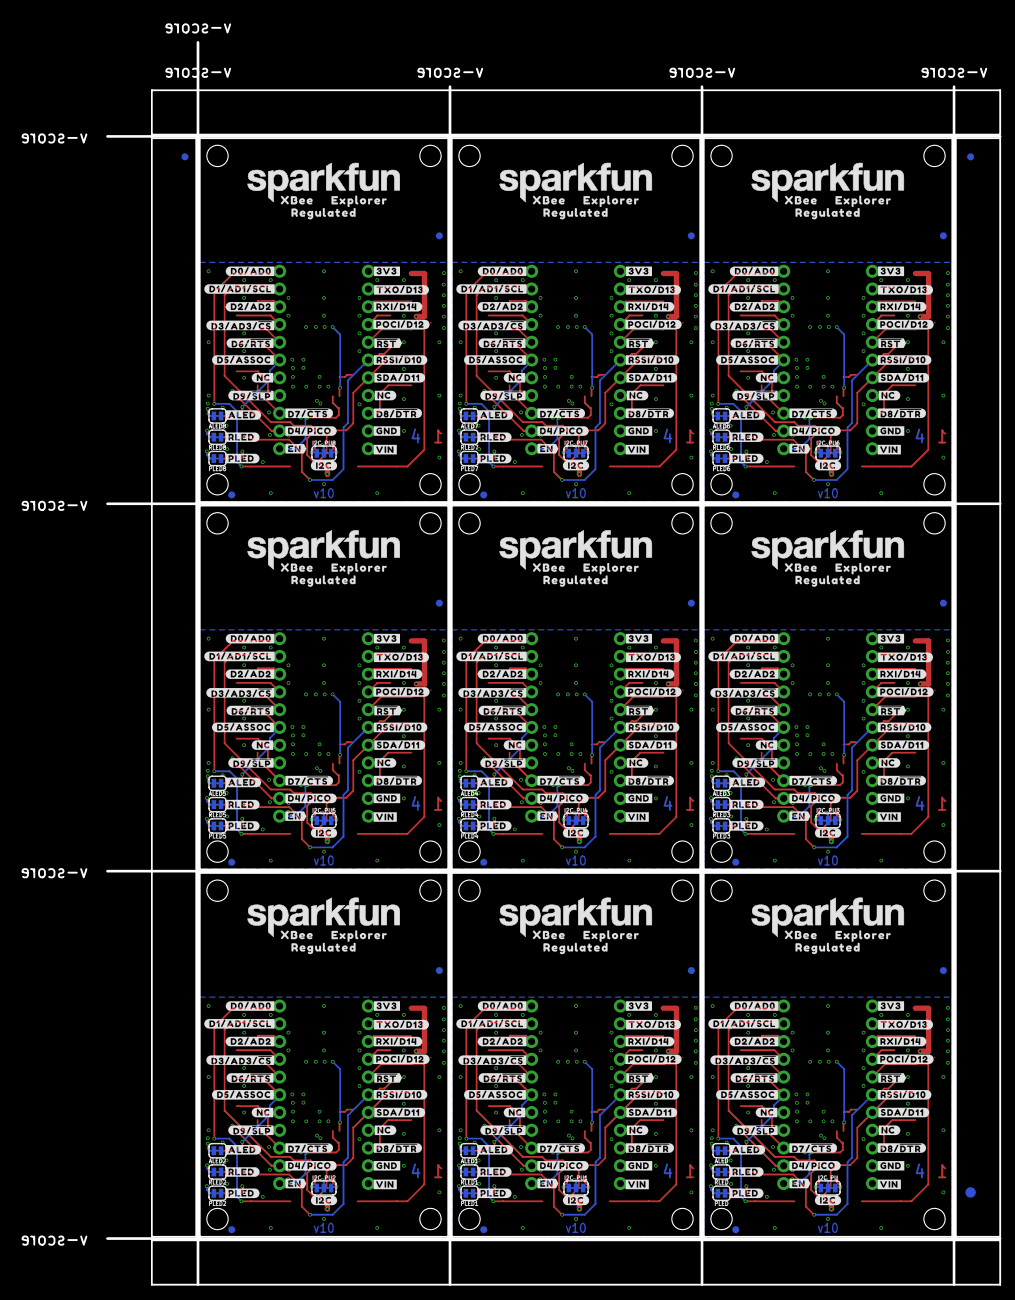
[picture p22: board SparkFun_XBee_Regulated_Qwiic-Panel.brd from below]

Board: 4 copper layers, 127.8 x 177.8 mm, 879 parts (327 on the bottom side), 270 nets.

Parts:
ALED, ALED1, ALED2, ALED3, ALED4, ALED5, ALED6, ALED7, ALED8: JUMPER-SMT_2_NC_TRACE_SILK; SMT-JUMPER_2_NC_TRACE_SILK
C1, C14, C24, C34, C44, C54, C64, C74, C84: 10uF; 1210
C2, C4, C12, C13, C22, C23, C32, C33, C42, C43, C52, C53, C62, C63, C72, C73, C82, C83: 22uF; 0603
C3, C9, C11, C17, C21, C27, C31, C37, C41, C47, C51, C57, C61, C67, C71, C77, C81, C87: 0.1uF; 0603
C5, C19, C29, C39, C49, C59, C69, C79, C89: 47pF; 0603
C6, C7, C15, C16, C25, C26, C35, C36, C45, C46, C55, C56, C65, C66, C75, C76, C85, C86: 10nF; 0603
C8, C20, C30, C40, C50, C60, C70, C80, C90: 10pF; 0603
C10, C18, C28, C38, C48, C58, C68, C78, C88: 10uF; 0603
D1, D2, D7, D10, D13, D16, D19, D22, D25: RED; LED-0603
D3, D5, D8, D11, D14, D17, D20, D23, D26: BLUE; LED-0603
D4, D6, D9, D12, D15, D18, D21, D24, D27: Yellow; LED-0603
E$1, E$2, E$3, E$4: FIDUCIAL-1X2
E$5, E$6: FIDUCIAL-1.5X3
FD1, FD2, FD3, FD4, FD5, FD6, FD7, FD8, FD9, FD10, FD11, FD12, FD13, FD14, FD15, FD16, FD17, FD18, FD19, FD20, FD21, FD22, FD23, FD24, FD25, FD26, FD27, FD28, FD29, FD30, FD31, FD32, FD33, FD34, FD35, FD36: FIDUCIAL1X2; FIDUCIAL-1X2
FRAME1, FRAME2, FRAME3, FRAME4, FRAME5, FRAME6, FRAME7, FRAME8, FRAME9: FRAME-LETTER; CREATIVE_COMMONS
H1, H2, H3, H4, H5, H6, H7, H8, H9, H10, H11, H12, H13, H14, H15, H16, H17, H18, H19, H20, H21, H22, H23, H24, H25, H26, H27, H28, H29, H30, H31, H32, H33, H34, H35, H36: STAND-OFFTIGHT; STAND-OFF-TIGHT
I2C_PU, I2C_PU1, I2C_PU2, I2C_PU3, I2C_PU4, I2C_PU5, I2C_PU6, I2C_PU7, I2C_PU8: JUMPER-SMT_3_2-NC_TRACE_SILK; SMT-JUMPER_3_2-NC_TRACE_SILK
J1, J3, J11, J12, J17, J18, J23, J24, J29, J30, J35, J36, J41, J42, J47, J48, J53, J54: 1X01_NO_SILK_STAND
J2, J10, J16, J22, J28, J34, J40, J46, J52: XBEE3-SMD
J4, J7, J13, J19, J25, J31, J37, J43, J49: QWIIC_RIGHT_ANGLE; JST04_1MM_RA
J5, J6, J8, J9, J14, J15, J20, J21, J26, J27, J32, J33, J38, J39, J44, J45, J50, J51: 1X10_NO_SILK
L1, L2, L3, L4, L5, L6, L7, L8, L9: 3.9UH; INDUCTOR_3.9UH
LOGO1, LOGO2, LOGO7, LOGO10, LOGO13, LOGO16, LOGO19, LOGO22, LOGO25: OSHW-LOGOS; OSHW-LOGO-S
LOGO3, LOGO5, LOGO8, LOGO11, LOGO14, LOGO17, LOGO20, LOGO23, LOGO26: QWIIC_LOGO_4MM; QWIIC_4MM
LOGO4, LOGO6, LOGO9, LOGO12, LOGO15, LOGO18, LOGO21, LOGO24, LOGO27: SFE_LOGO_NAMEBLANK; BLANK
PLED, PLED1, PLED2, PLED3, PLED4, PLED5, PLED6, PLED7, PLED8: JUMPER-SMT_2_NC_TRACE_SILK; SMT-JUMPER_2_NC_TRACE_SILK
R1, R2, R4, R6, R8, R9, R10, R12, R14, R15, R16, R18, R19, R20, R22, R24, R25, R26, R28, R30, R31, R32, R34, R36, R37, R38, R40, R42, R43, R44, R46, R48, R49, R50, R52, R54: 2.2k; 0603
R3, R7, R17, R23, R29, R35, R41, R47, R53: 10k; 0603
R5, R11, R13, R21, R27, R33, R39, R45, R51: 4.7k; 0603
RLED, RLED1, RLED2, RLED3, RLED4, RLED5, RLED6, RLED7, RLED8: JUMPER-SMT_2_NC_TRACE_SILK; SMT-JUMPER_2_NC_TRACE_SILK
S1, S2, S3, S4, S5, S6, S7, S8, S9, S10, S11, S12, S13, S14, S15, S16, S17, S18: TACTILE_SWITCH_SMD_5.2MM
U1, U2, U3, U4, U5, U6, U7, U8, U9: AP63203; SOT23-6
U$1, U$12, U$69, U$87, U$121, U$139, U$173, U$191, U$225, U$243, U$277, U$295, U$329, U$347, U$381, U$399, U$433, U$451: #GND#0
U$2, U$53, U$63, U$88, U$113, U$140, U$165, U$192, U$217, U$244, U$269, U$296, U$321, U$348, U$373, U$400, U$425, U$452: SFE_LOGO_NAME_.2
U$3, U$6, U$89, U$102, U$141, U$154, U$193, U$206, U$245, U$258, U$297, U$310, U$349, U$362, U$401, U$414, U$453, U$466: #EN#17
U$4, U$90, U$142, U$194, U$246, U$298, U$350, U$402, U$454: #NC#1
U$5, U$91, U$143, U$195, U$247, U$299, U$351, U$403, U$455: #NC#3
U$7, U$92, U$144, U$196, U$248, U$300, U$352, U$404, U$456: #D7##CTS##26
U$8, U$56, U$116, U$168, U$220, U$272, U$324, U$376, U$428: #D0#AD0#18
U$9, U$37, U$44, U$47, U$105, U$109, U$157, U$161, U$209, U$213, U$261, U$265, U$313, U$317, U$365, U$369, U$417, U$421: #3V3#1
U$10, U$93, U$145, U$197, U$249, U$301, U$353, U$405, U$457: #D4#PICO#25
U$11, U$100, U$152, U$204, U$256, U$308, U$360, U$412, U$464: #RLED#22
U$13, U$70, U$122, U$174, U$226, U$278, U$330, U$382, U$434: #D8##DTR##27
U$14, U$71, U$123, U$175, U$227, U$279, U$331, U$383, U$435: #RSSI#D10#17
U$15, U$72, U$124, U$176, U$228, U$280, U$332, U$384, U$436: #SDA#D11#9
U$16, U$73, U$125, U$177, U$229, U$281, U$333, U$385, U$437: ##RST##15
U$17, U$74, U$126, U$178, U$230, U$282, U$334, U$386, U$438: #POCI#D12#24
U$18, U$75, U$127, U$179, U$231, U$283, U$335, U$387, U$439: #RXI#D14#15
U$19, U$57, U$117, U$169, U$221, U$273, U$325, U$377, U$429: #D2#AD2#19
U$20, U$58, U$118, U$170, U$222, U$274, U$326, U$378, U$430: #D6##RTS##25
U$21, U$79, U$131, U$183, U$235, U$287, U$339, U$391, U$443: #TXO#8
U$22, U$76, U$128, U$180, U$232, U$284, U$336, U$388, U$440: #TXO#D13#13
U$23, U$33, U$103, U$104, U$155, U$156, U$207, U$208, U$259, U$260, U$311, U$312, U$363, U$364, U$415, U$416, U$467, U$468: EXPLORER1344
U$24, U$29, U$94, U$97, U$146, U$149, U$198, U$201, U$250, U$253, U$302, U$305, U$354, U$357, U$406, U$409, U$458, U$461: REGULATED1343
U$25, U$28, U$95, U$96, U$147, U$148, U$199, U$200, U$251, U$252, U$303, U$304, U$355, U$356, U$407, U$408, U$459, U$460: XBEE340
U$26, U$38, U$106, U$158, U$210, U$262, U$314, U$366, U$418: #I2C#33
U$27, U$80, U$132, U$184, U$236, U$288, U$340, U$392, U$444: #RXI#7
U$30, U$51, U$112, U$164, U$216, U$268, U$320, U$372, U$424: #RST#30
U$31, U$65, U$85, U$98, U$137, U$150, U$189, U$202, U$241, U$254, U$293, U$306, U$345, U$358, U$397, U$410, U$449, U$462: #D0#3
U$32, U$99, U$151, U$203, U$255, U$307, U$359, U$411, U$463: #D1#AD1#SCL#8
U$34, U$101, U$153, U$205, U$257, U$309, U$361, U$413, U$465: #D3#AD3##CS##23
U$35, U$67, U$119, U$171, U$223, U$275, U$327, U$379, U$431: #D5#ASSOC#25
U$36, U$68, U$120, U$172, U$224, U$276, U$328, U$380, U$432: #D9##SLP##28
U$39, U$42, U$107, U$159, U$211, U$263, U$315, U$367, U$419: PWR26
U$40, U$50, U$111, U$163, U$215, U$267, U$319, U$371, U$423: D03
U$41, U$43, U$108, U$160, U$212, U$264, U$316, U$368, U$420: ASSOC27
U$45, U$81, U$133, U$185, U$237, U$289, U$341, U$393, U$445: #POCI#32
U$46, U$48, U$66, U$86, U$110, U$138, U$162, U$190, U$214, U$242, U$266, U$294, U$318, U$346, U$370, U$398, U$422, U$450: #VIN#4
U$49, U$77, U$129, U$181, U$233, U$285, U$337, U$389, U$441: #ALED#21
U$52, U$78, U$130, U$182, U$234, U$286, U$338, U$390, U$442: #PLED#20
U$54, U$61, U$114, U$166, U$218, U$270, U$322, U$374, U$426: SFE_LOGO_FLAME_.2
U$55, U$62, U$115, U$167, U$219, U$271, U$323, U$375, U$427: RSSI31
U$59, U$82, U$134, U$186, U$238, U$290, U$342, U$394, U$446: ##CS##26
U$60, U$83, U$135, U$187, U$239, U$291, U$343, U$395, U$447: #SCLK#33
U$64, U$84, U$136, U$188, U$240, U$292, U$344, U$396, U$448: #SCL#9

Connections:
3.3V: C2.1, C4.1, C5.1, C7.1, C8.1, C9.1, C10.1, I2C_PU.2, J2.1, J4.2, J6.1, L1.P$2, R11.1, U2.1
3.3V1: C12.1, C13.1, C16.1, C17.1, C18.1, C19.1, C20.1, I2C_PU1.2, J7.2, J9.1, J10.1, L2.P$2, R5.1, U1.1
3.3V2: C22.1, C23.1, C26.1, C27.1, C28.1, C29.1, C30.1, I2C_PU2.2, J13.2, J15.1, J16.1, L3.P$2, R13.1, U3.1
3.3V3: C32.1, C33.1, C36.1, C37.1, C38.1, C39.1, C40.1, I2C_PU3.2, J19.2, J21.1, J22.1, L4.P$2, R21.1, U4.1
3.3V4: C42.1, C43.1, C46.1, C47.1, C48.1, C49.1, C50.1, I2C_PU4.2, J25.2, J27.1, J28.1, L5.P$2, R27.1, U5.1
3.3V5: C52.1, C53.1, C56.1, C57.1, C58.1, C59.1, C60.1, I2C_PU5.2, J31.2, J33.1, J34.1, L6.P$2, R33.1, U6.1
3.3V6: C62.1, C63.1, C66.1, C67.1, C68.1, C69.1, C70.1, I2C_PU6.2, J37.2, J39.1, J40.1, L7.P$2, R39.1, U7.1
3.3V7: C72.1, C73.1, C76.1, C77.1, C78.1, C79.1, C80.1, I2C_PU7.2, J43.2, J45.1, J46.1, L8.P$2, R45.1, U8.1
3.3V8: C82.1, C83.1, C86.1, C87.1, C88.1, C89.1, C90.1, I2C_PU8.2, J49.2, J51.1, J52.1, L9.P$2, R51.1, U9.1
!RESET!: C6.1, J2.5, J6.5, S1.1, S1.2
!RESET!1: C15.1, J9.5, J10.5, S3.1, S3.2
!RESET!2: C25.1, J15.5, J16.5, S5.1, S5.2
!RESET!3: C35.1, J21.5, J22.5, S7.1, S7.2
!RESET!4: C45.1, J27.5, J28.5, S9.1, S9.2
!RESET!5: C55.1, J33.5, J34.5, S11.1, S11.2
!RESET!6: C65.1, J39.5, J40.5, S13.1, S13.2
!RESET!7: C75.1, J45.5, J46.5, S15.1, S15.2
!RESET!8: C85.1, J51.5, J52.5, S17.1, S17.2
D0: J2.20, J5.1, S2.1, S2.2
D1: J8.1, J10.20, S4.1, S4.2
D1/SCL: J2.19, J4.4, J5.2, R15.1
D1/SCL1: J7.4, J8.2, J10.19, R4.1
D1/SCL2: J13.4, J14.2, J16.19, R10.1
D1/SCL3: J19.4, J20.2, J22.19, R20.1
D1/SCL4: J25.4, J26.2, J28.19, R26.1
D1/SCL5: J31.4, J32.2, J34.19, R32.1
D1/SCL6: J37.4, J38.2, J40.19, R38.1
D1/SCL7: J43.4, J44.2, J46.19, R44.1
D1/SCL8: J49.4, J50.2, J52.19, R50.1
D2: J14.1, J16.20, S6.1, S6.2
D2/SPI_CLK: J2.18, J5.3
D2/SPI_CLK1: J8.3, J10.18
D2/SPI_CLK2: J14.3, J16.18
D2/SPI_CLK3: J20.3, J22.18
D2/SPI_CLK4: J26.3, J28.18
D2/SPI_CLK5: J32.3, J34.18
D2/SPI_CLK6: J38.3, J40.18
D2/SPI_CLK7: J44.3, J46.18
D2/SPI_CLK8: J50.3, J52.18
D3: J20.1, J22.20, S8.1, S8.2
D3/SPI_!CS!: J2.17, J5.4
D3/SPI_!CS!1: J8.4, J10.17
D3/SPI_!CS!2: J14.4, J16.17
D3/SPI_!CS!3: J20.4, J22.17
D3/SPI_!CS!4: J26.4, J28.17
D3/SPI_!CS!5: J32.4, J34.17
D3/SPI_!CS!6: J38.4, J40.17
D3/SPI_!CS!7: J44.4, J46.17
D3/SPI_!CS!8: J50.4, J52.17
D4: J26.1, J28.20, S10.1, S10.2
D4/SPI_PICO: J2.11, J5.10
D4/SPI_PICO1: J8.10, J10.11
D4/SPI_PICO2: J14.10, J16.11
D4/SPI_PICO3: J20.10, J22.11
D4/SPI_PICO4: J26.10, J28.11
D4/SPI_PICO5: J32.10, J34.11
D4/SPI_PICO6: J38.10, J40.11
D4/SPI_PICO7: J44.10, J46.11
D4/SPI_PICO8: J50.10, J52.11
D5: J32.1, J34.20, S12.1, S12.2
D5/ASSOCIATE: J2.15, J5.6, R12.1
D5/ASSOCIATE1: J8.6, J10.15, R6.1
D5/ASSOCIATE2: J14.6, J16.15, R16.1
D5/ASSOCIATE3: J20.6, J22.15, R22.1
D5/ASSOCIATE4: J26.6, J28.15, R28.1
D5/ASSOCIATE5: J32.6, J34.15, R34.1
D5/ASSOCIATE6: J38.6, J40.15, R40.1
D5/ASSOCIATE7: J44.6, J46.15, R46.1
D5/ASSOCIATE8: J50.6, J52.15, R52.1
D6: J38.1, J40.20, S14.1, S14.2
D6/!RTS!: J2.16, J5.5
D6/!RTS!1: J8.5, J10.16
D6/!RTS!2: J14.5, J16.16
D6/!RTS!3: J20.5, J22.16
D6/!RTS!4: J26.5, J28.16
D6/!RTS!5: J32.5, J34.16
D6/!RTS!6: J38.5, J40.16
D6/!RTS!7: J44.5, J46.16
D6/!RTS!8: J50.5, J52.16
D7: J44.1, J46.20, S16.1, S16.2
D7/!CTS!: J2.12, J5.9
D7/!CTS!1: J8.9, J10.12
D7/!CTS!2: J14.9, J16.12
D7/!CTS!3: J20.9, J22.12
D7/!CTS!4: J26.9, J28.12
D7/!CTS!5: J32.9, J34.12
D7/!CTS!6: J38.9, J40.12
D7/!CTS!7: J44.9, J46.12
D7/!CTS!8: J50.9, J52.12
D8: J50.1, J52.20, S18.1, S18.2
D8/!DTR!: J2.9, J6.9
D8/!DTR!1: J9.9, J10.9
D8/!DTR!2: J15.9, J16.9
D8/!DTR!3: J21.9, J22.9
D8/!DTR!4: J27.9, J28.9
D8/!DTR!5: J33.9, J34.9
D8/!DTR!6: J39.9, J40.9
D8/!DTR!7: J45.9, J46.9
D8/!DTR!8: J51.9, J52.9
D9/!SLEEP!: J2.13, J5.8
D9/!SLEEP!1: J8.8, J10.13
D9/!SLEEP!2: J14.8, J16.13
D9/!SLEEP!3: J20.8, J22.13
D9/!SLEEP!4: J26.8, J28.13
D9/!SLEEP!5: J32.8, J34.13
D9/!SLEEP!6: J38.8, J40.13
D9/!SLEEP!7: J44.8, J46.13
D9/!SLEEP!8: J50.8, J52.13
D10/RSSI_PWM: J2.6, J6.6, R2.1
D10/RSSI_PWM1: J9.6, J10.6, R8.1
D10/RSSI_PWM2: J15.6, J16.6, R18.1
D10/RSSI_PWM3: J21.6, J22.6, R24.1
D10/RSSI_PWM4: J27.6, J28.6, R30.1
D10/RSSI_PWM5: J33.6, J34.6, R36.1
D10/RSSI_PWM6: J39.6, J40.6, R42.1
D10/RSSI_PWM7: J45.6, J46.6, R48.1
D10/RSSI_PWM8: J51.6, J52.6, R54.1
D11/SDA: J2.7, J4.3, J6.7, R14.1
D11/SDA1: J7.3, J9.7, J10.7, R1.1
D11/SDA2: J13.3, J15.7, J16.7, R9.1
D11/SDA3: J19.3, J21.7, J22.7, R19.1
D11/SDA4: J25.3, J27.7, J28.7, R25.1
D11/SDA5: J31.3, J33.7, J34.7, R31.1
D11/SDA6: J37.3, J39.7, J40.7, R37.1
D11/SDA7: J43.3, J45.7, J46.7, R43.1
D11/SDA8: J49.3, J51.7, J52.7, R49.1
D12/SPI_POCI: J2.4, J6.4
D12/SPI_POCI1: J9.4, J10.4
D12/SPI_POCI2: J15.4, J16.4
D12/SPI_POCI3: J21.4, J22.4
D12/SPI_POCI4: J27.4, J28.4
D12/SPI_POCI5: J33.4, J34.4
D12/SPI_POCI6: J39.4, J40.4
D12/SPI_POCI7: J45.4, J46.4
D12/SPI_POCI8: J51.4, J52.4
D13/TXO: J2.2, J6.2
D13/TXO1: J9.2, J10.2
D13/TXO2: J15.2, J16.2
D13/TXO3: J21.2, J22.2
D13/TXO4: J27.2, J28.2
D13/TXO5: J33.2, J34.2
D13/TXO6: J39.2, J40.2
D13/TXO7: J45.2, J46.2
D13/TXO8: J51.2, J52.2
D14/RXI: J2.3, J6.3
D14/RXI1: J9.3, J10.3
D14/RXI2: J15.3, J16.3
D14/RXI3: J21.3, J22.3
D14/RXI4: J27.3, J28.3
D14/RXI5: J33.3, J34.3
D14/RXI6: J39.3, J40.3
D14/RXI7: J45.3, J46.3
D14/RXI8: J51.3, J52.3
EN: J1.1, R3.1, U2.2
EN1: J11.1, R7.1, U1.2
EN2: J17.1, R17.1, U3.2
EN3: J23.1, R23.1, U4.2
EN4: J29.1, R29.1, U5.2
EN5: J35.1, R35.1, U6.2
EN6: J41.1, R41.1, U7.2
EN7: J47.1, R47.1, U8.2
EN8: J53.1, R53.1, U9.2
GND: ALED.1, C1.2, C2.2, C4.2, C5.2, C6.2, C7.2, C8.2, C9.2, C10.2, J2.10, J4.1, J6.10, PLED.1, RLED.1, S1.3, S1.4, S2.3, S2.4, U2.4
GND1: ALED1.1, C12.2, C13.2, C14.2, C15.2, C16.2, C17.2, C18.2, C19.2, C20.2, J7.1, J9.10, J10.10, PLED1.1, RLED1.1, S3.3, S3.4, S4.3, S4.4, U1.4
GND2: ALED2.1, C22.2, C23.2, C24.2, C25.2, C26.2, C27.2, C28.2, C29.2, C30.2, J13.1, J15.10, J16.10, PLED2.1, RLED2.1, S5.3, S5.4, S6.3, S6.4, U3.4
GND3: ALED3.1, C32.2, C33.2, C34.2, C35.2, C36.2, C37.2, C38.2, C39.2, C40.2, J19.1, J21.10, J22.10, PLED3.1, RLED3.1, S7.3, S7.4, S8.3, S8.4, U4.4
GND4: ALED4.1, C42.2, C43.2, C44.2, C45.2, C46.2, C47.2, C48.2, C49.2, C50.2, J25.1, J27.10, J28.10, PLED4.1, RLED4.1, S9.3, S9.4, S10.3, S10.4, U5.4
GND5: ALED5.1, C52.2, C53.2, C54.2, C55.2, C56.2, C57.2, C58.2, C59.2, C60.2, J31.1, J33.10, J34.10, PLED5.1, RLED5.1, S11.3, S11.4, S12.3, S12.4, U6.4
GND6: ALED6.1, C62.2, C63.2, C64.2, C65.2, C66.2, C67.2, C68.2, C69.2, C70.2, J37.1, J39.10, J40.10, PLED6.1, RLED6.1, S13.3, S13.4, S14.3, S14.4, U7.4
GND7: ALED7.1, C72.2, C73.2, C74.2, C75.2, C76.2, C77.2, C78.2, C79.2, C80.2, J43.1, J45.10, J46.10, PLED7.1, RLED7.1, S15.3, S15.4, S16.3, S16.4, U8.4
GND8: ALED8.1, C82.2, C83.2, C84.2, C85.2, C86.2, C87.2, C88.2, C89.2, C90.2, J49.1, J51.10, J52.10, PLED8.1, RLED8.1, S17.3, S17.4, S18.3, S18.4, U9.4
unnamed: C3.1, U2.6
unnamed: D4.A, R2.2
unnamed: D4.C, RLED.2
unnamed: I2C_PU1.3, R1.2
unnamed: I2C_PU1.1, R4.2
unnamed: D1.A, R5.2
unnamed: D2.A, R11.2
unnamed: C3.2, L1.P$1, U2.5
unnamed: D5.A, R6.2
unnamed: ALED1.2, D5.C
unnamed: I2C_PU.3, R14.2
unnamed: D3.A, R12.2
unnamed: I2C_PU.1, R15.2
unnamed: D1.C, PLED1.2
unnamed: C11.1, U1.6
unnamed: C11.2, L2.P$1, U1.5
unnamed: D6.A, R8.2
unnamed: D6.C, RLED1.2
unnamed: I2C_PU2.3, R9.2
unnamed: I2C_PU2.1, R10.2
unnamed: ALED.2, D3.C
unnamed: D7.A, R13.2
unnamed: D2.C, PLED.2
unnamed: D8.A, R16.2
unnamed: ALED2.2, D8.C
unnamed: D7.C, PLED2.2
unnamed: C21.1, U3.6
unnamed: C21.2, L3.P$1, U3.5
unnamed: D9.A, R18.2
unnamed: D9.C, RLED2.2
unnamed: I2C_PU3.3, R19.2
unnamed: I2C_PU3.1, R20.2
unnamed: D10.A, R21.2
unnamed: D11.A, R22.2
unnamed: ALED3.2, D11.C
unnamed: D10.C, PLED3.2
unnamed: C31.1, U4.6
unnamed: C31.2, L4.P$1, U4.5
unnamed: D12.A, R24.2
unnamed: D12.C, RLED3.2
unnamed: I2C_PU4.3, R25.2
unnamed: I2C_PU4.1, R26.2
unnamed: D13.A, R27.2
unnamed: D14.A, R28.2
unnamed: ALED4.2, D14.C
unnamed: D13.C, PLED4.2
unnamed: C41.1, U5.6
unnamed: C41.2, L5.P$1, U5.5
unnamed: D15.A, R30.2
unnamed: D15.C, RLED4.2
unnamed: I2C_PU5.3, R31.2
unnamed: I2C_PU5.1, R32.2
unnamed: D16.A, R33.2
unnamed: D17.A, R34.2
unnamed: ALED5.2, D17.C
unnamed: D16.C, PLED5.2
unnamed: C51.1, U6.6
unnamed: C51.2, L6.P$1, U6.5
unnamed: D18.A, R36.2
unnamed: D18.C, RLED5.2
unnamed: I2C_PU6.3, R37.2
unnamed: I2C_PU6.1, R38.2
unnamed: D19.A, R39.2
unnamed: D20.A, R40.2
unnamed: ALED6.2, D20.C
unnamed: D19.C, PLED6.2
unnamed: C61.1, U7.6
unnamed: C61.2, L7.P$1, U7.5
unnamed: D21.A, R42.2
unnamed: D21.C, RLED6.2
unnamed: I2C_PU7.3, R43.2
unnamed: I2C_PU7.1, R44.2
unnamed: D22.A, R45.2
unnamed: D23.A, R46.2
unnamed: ALED7.2, D23.C
unnamed: D22.C, PLED7.2
unnamed: C71.1, U8.6
unnamed: C71.2, L8.P$1, U8.5
unnamed: D24.A, R48.2
unnamed: D24.C, RLED7.2
unnamed: I2C_PU8.3, R49.2
unnamed: I2C_PU8.1, R50.2
unnamed: D25.A, R51.2
unnamed: D26.A, R52.2
unnamed: ALED8.2, D26.C
unnamed: D25.C, PLED8.2
unnamed: C81.1, U9.6
unnamed: C81.2, L9.P$1, U9.5
unnamed: D27.A, R54.2
unnamed: D27.C, RLED8.2
VIN: C1.1, J3.1, R3.2, U2.3
VIN1: C14.1, J12.1, R7.2, U1.3
VIN2: C24.1, J18.1, R17.2, U3.3
VIN3: C34.1, J24.1, R23.2, U4.3
VIN4: C44.1, J30.1, R29.2, U5.3
VIN5: C54.1, J36.1, R35.2, U6.3
VIN6: C64.1, J42.1, R41.2, U7.3
VIN7: C74.1, J48.1, R47.2, U8.3
VIN8: C84.1, J54.1, R53.2, U9.3

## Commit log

2023-01-31 Routes the board (roughly)
    [SparkFun_XBee3_Cat1_Smart_Modem_Regulated.brd]
2023-01-31 Adds silk
    [SparkFun_XBee3_Cat1_Smart_Modem_Regulated.brd]
2023-01-31 MOves to a smaller schematic symbol, tries to make the associate LED visible
    [SparkFun_XBee3_Cat1_Smart_Modem_Regulated.brd, SparkFun_XBee3_Cat1_Smart_Modem_Regulated.sch]
2023-01-31 MOre vias
    [SparkFun_XBee3_Cat1_Smart_Modem_Regulated.brd, SparkFun_XBee3_Cat1_Smart_Modem_Regulated.sch]
2023-03-01 Adds two additional layers, routes all nets, adds most silk
    [SparkFun_XBee3_Cat1_Smart_Modem_Regulated.brd, SparkFun_XBee3_Cat1_Smart_Modem_Regulated.sch]
2023-03-01 Adds more silk labels, Adds ordering instructions
    [SparkFun_XBee3_Cat1_Smart_Modem_Regulated.brd, SparkFun_XBee3_Cat1_Smart_Modem_Regulated.sch]
2023-03-01 Moves some silk around
    [SparkFun_XBee3_Cat1_Smart_Modem_Regulated.brd]
2023-03-01 Adds four layer numbers, fixes accidental naming of GND to "OPEN"
    [SparkFun_XBee3_Cat1_Smart_Modem_Regulated.brd, SparkFun_XBee3_Cat1_Smart_Modem_Regulated.sch]
2023-03-01 Moves LEDs around for consistency with the development board
    [SparkFun_XBee3_Cat1_Smart_Modem_Regulated.brd]
2023-03-01 Approves DRC errors caused by jumpers
    [SparkFun_XBee3_Cat1_Smart_Modem_Regulated.brd]
2023-03-02 Adds vias, fixes acid traps, moves LEDs away from the edge
    [SparkFun_XBee3_Cat1_Smart_Modem_Regulated.brd, SparkFun_XBee3_Cat1_Smart_Modem_Regulated.sch]
2023-03-02 Moves I2C jumper down to make more space for the silk in that area
    [SparkFun_XBee3_Cat1_Smart_Modem_Regulated.brd, SparkFun_XBee3_Cat1_Smart_Modem_Regulated.sch]
2023-03-02 Adds vias!!
    [SparkFun_XBee3_Cat1_Smart_Modem_Regulated.brd]
2023-03-03 Renames board files
    [SparkFun_XBee_Regulated_Qwiic.brd, SparkFun_XBee_Regulated_Qwiic.sch]
2023-03-03 Adds production panels
    [SparkFun_XBee_Regulated_Qwiic-Panel.GBL, SparkFun_XBee_Regulated_Qwiic-Panel.GBO, SparkFun_XBee_Regulated_Qwiic-Panel.GBP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]
2023-03-08 Adds "Explorer" to silk
    [SparkFun_XBee_Regulated_Qwiic.brd]
2023-03-08 Updates silk on production files
    [SparkFun_XBee_Regulated_Qwiic-Panel.brd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]
2024-01-02 Adding buck converter image
2024-01-05 Updates to Product trademarks per Digi
    [SparkFun_Digi_XBee_Regulated_Qwiic.brd, SparkFun_Digi_XBee_Regulated_Qwiic.sch]

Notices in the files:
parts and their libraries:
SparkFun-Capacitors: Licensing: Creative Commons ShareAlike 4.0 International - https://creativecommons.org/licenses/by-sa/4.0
